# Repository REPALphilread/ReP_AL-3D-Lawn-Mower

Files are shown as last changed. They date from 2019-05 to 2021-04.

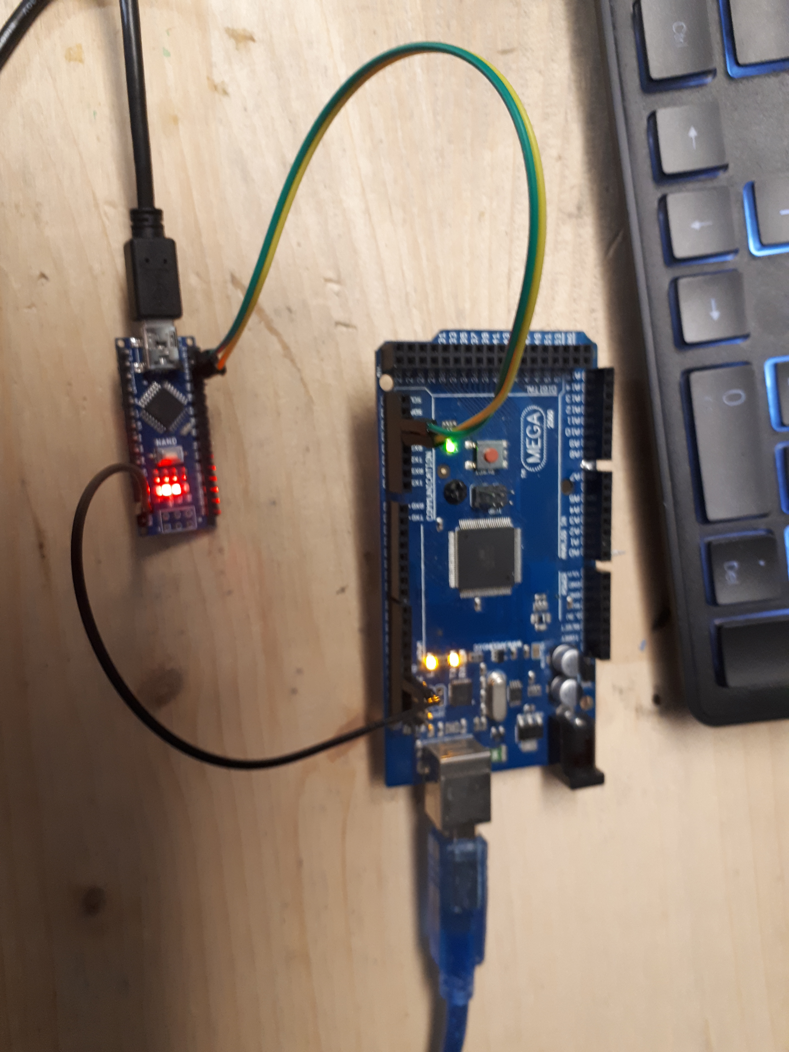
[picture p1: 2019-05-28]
Test Sketches/Test Coms MEGA NANO/MEGA NANO Setup.jpg

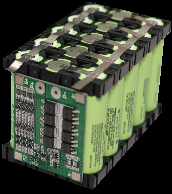
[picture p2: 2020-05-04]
Mower Arduino Code/Mower_V9.2/SDCard BMP/batterypack.bmp

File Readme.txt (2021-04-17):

ReP_AL-3D-Lawn-Mower
Code and Files for the ReP_AL 3D Printed Lawn Mower
---------------------------------------------------

All build instructions and the latest STL files are found at

www.repalmakershop.com

Arduino Code
------------
The mower software is in the folder Mower Arduino Code:  
PLEASE ALWAYS USE THE LATEST VERSION OF THE CODE

Upload the MEGA code to the Arduino MEGA
Upload the Nano code to the Arduino Nano
Upload the NodeMCU code to the NodeMCU Board   (includes new code)
Upload the TFT Code to the TFT MEGA Shield
Upload the ESP32_Rover Code to the ESP32 Board (GPS)
Upload the BMP Files to the TFT SD Card

(I needed to use the "old bootloader" option in the Arduino IDE to get the sketch to upload to the NANO)
Perimeter Wire - Sender_station_V1 needs to be uploaded to the Arduino in the perimeter wire transmitter.

Perimeter Wire Transmitter
--------------------------

Upload the code from this folder to the wire transmitter

Libraries
---------
All the libraries I used for the Arduino Code can be found in this folder.
Ensure these are installed in the Arduino libraries folder otherwise the main code wont compile

Test sketches folder
--------------------
They are designed to test the indiviual components in your build to see if they are working. 
Ihe idea is to debug the components indicudually so you are faster in completing the project.

----------------------------------------------
All my work falls under the GNU Public License
----------------------------------------------

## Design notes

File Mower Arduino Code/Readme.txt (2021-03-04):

---------------------------------------------
This software is protected by the GNU License
---------------------------------------------

PLEASE ALWAYS USE THE LATEST VERSION OF THE CODE!!

Upload the MEGA code to the Arduino MEGA
Upload the Nano code to the Arduino Nano
Upload the NodeMCU code to the NodeMCU Board   (includes new code)
Upload the TFT Code to the TFT MEGA Shield
Upload the ESP32_Rover Code to the ESP32 Board (if using GPS)
Upload the BMP Files to the TFT SD Card

Newest Code Version 9.2    Uploaded 04.03.2020
Please use this version

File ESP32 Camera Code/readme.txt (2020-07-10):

The WEB_CAM Code creates a camera server on the home network.
This allows a high resolution video feed.

The CAM_Blynk code alows the video to be viewed in the Blynk APP.
The video feed can also be viewed in a WEB Browser.
Resolution on this version is poor.

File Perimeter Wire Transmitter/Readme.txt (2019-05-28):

Upload this code to the Arduino in the perimeter wire transmitter station.

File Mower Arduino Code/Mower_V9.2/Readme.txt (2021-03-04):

ReP_AL 3D Printed Robot Lawn Mower
----------------------------------

Code V9.2  10.01.2021
----------------------

Upload the MEGA code to the Arduino MEGA
Upload the Nano code to the Arduino Nano
Upload the NodeMCU code to the NodeMCU Board   (includes new code)
Upload the TFT Code to the TFT MEGA Shield
Upload the ESP32_Rover Code to the ESP32 Board (GPS)
Upload the BMP Files to the TFT SD Card

Features of 9.2
---------------

- Allows all LCD messages to be turned off if using a TFT screen.  This makes the program much more compact when using a TFT screen

In MEGA code line 11
set //#define LCD_KEYPAD for no LCD message
set #define LCD_KEYPAD for LCD messages on

- Major bug fix in the sensors menu.  Now SONAR and WIFI can be accessed again.

Known Issues of 9.0
--------------------
- Communication of button posiitons in the WIFI app not perfected.
- GYRO control not optimised.

Planned for next release
------------------------
- GYRO / Compass options (which device will control the mower)

NodeMCU Board URL:
------------------
Use this URL to add the NodeMCU board 1.0 to the boards menu.

http://arduino.esp8266.com/stable/package_esp8266com_index.json

ESP32 Board URL:
------------------
Use this URL to add the ESP32 DOITDev1.0 board to the boards menu.
https://dl.espressif.com/dl/package_esp32_index.json, http://arduino.esp8266.com/stable/package_esp8266com_index.json

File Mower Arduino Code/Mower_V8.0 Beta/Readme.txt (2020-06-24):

ReP_AL 3D Printed Robot Lawn Mower
----------------------------------

DONT USE THIS VERSION - USE THE 8.2 Version

Code V8.0  BETA    04.05.2020
------------------------------

Upload the MEGA code to the Arduino MEGA
Upload the Nano code to the Arduino Nano
Upload the NodeMCU code to the NodeMCU Board   (includes new code)
Upload the TFT Code to the TFT MEGA Shield
Upload the BMP Files to the TFT SD Card (in the route folder of the SD card)

Features of 8.0 BETA
--------------------

- TFT Display is added (TFT_Screen_Menu = 1 in Settings to turn on TFT function
			Ensure LCD_Scree_Keypad_Menu = 0 )
- Bumper Bar is activated in finding wire function
- Angle Stop Capability added
- Tip Over Safety Stop Capability added

Experimental
- Slow at wire function - Slows the mower when it gets to the wire to ensure the wire is detected in time.

Known Issues of 8.0 BETA
------------------------
- With TFT longer reaction time than normal to detect wire (see slow at wire function to help)
- TFT Some menus get stuck when returning to the home screen
- TFT Test scripts dont always start correctly

NodeMCU Board URL:
------------------
Use this URL to add the NodeMCU board 1.0 to the boards menu.

http://arduino.esp8266.com/stable/package_esp8266com_index.json

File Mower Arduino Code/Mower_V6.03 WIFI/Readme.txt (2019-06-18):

ReP_AL 3D Printed Robot Lawn Mower
----------------------------------

Code V6.03   
------------------------------

Upload the MEGA code to the Arduino MEGA
Upload the Nano code to the Arduino Nano
Upload the NodeMCU code to the NodeMCU Board

Features of 6.03
----------------

- Improved docking logic
- Docking can now be cancelled with the APP by pressing pause.
- Compass now uses degrees instead of heading for heading lock motion (better stability)
- Max_Cycle_Wire_Find set this for the maximum amount of cycles the mower moves forward to find the wire before reseting.

NodeMCU Board URL:
http://arduino.esp8266.com/stable/package_esp8266com_index.json

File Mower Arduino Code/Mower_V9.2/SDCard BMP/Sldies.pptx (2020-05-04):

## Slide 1

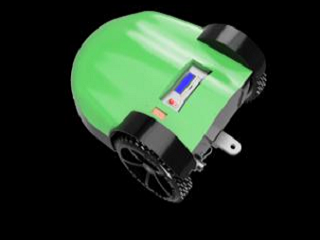
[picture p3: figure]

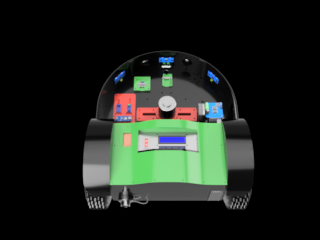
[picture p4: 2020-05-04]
Mower Arduino Code/Mower_V9.2/SDCard BMP/Sensors.bmp

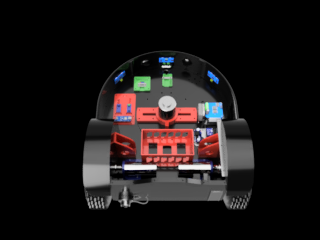
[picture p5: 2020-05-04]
Mower Arduino Code/Mower_V9.2/SDCard BMP/Motors.bmp

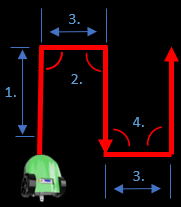
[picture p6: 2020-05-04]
Mower Arduino Code/Mower_V9.2/SDCard BMP/ParallelMow.bmp

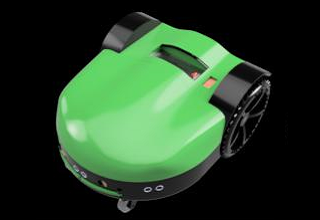
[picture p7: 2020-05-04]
Mower Arduino Code/Mower_V9.2/SDCard BMP/Mower4.bmp

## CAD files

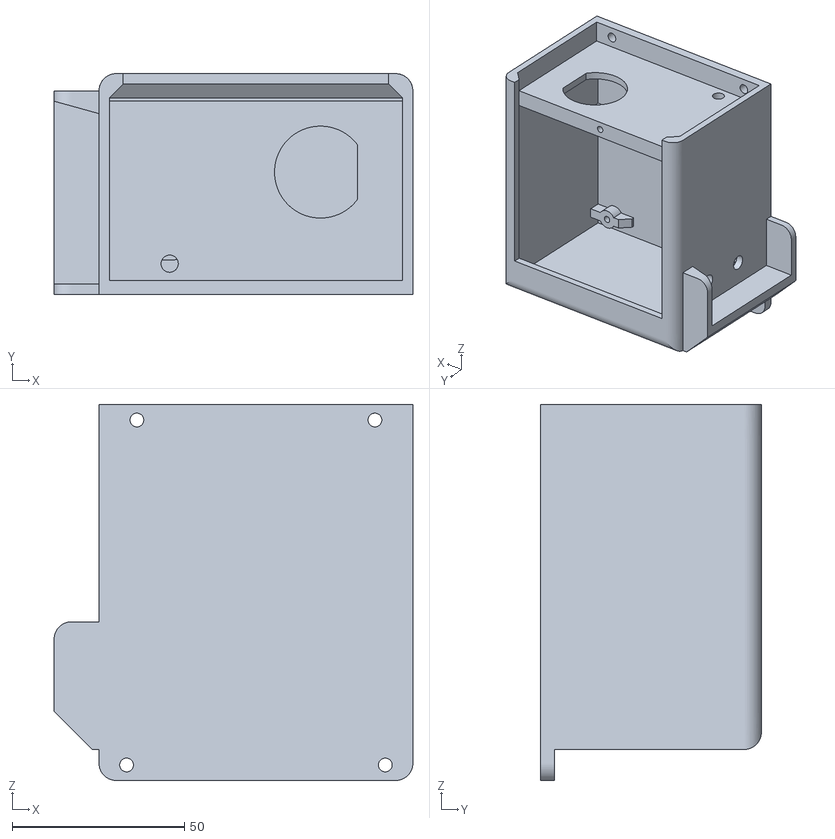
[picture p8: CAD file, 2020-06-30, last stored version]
RTK GPS STL Files/STL RTK Base Station Case/01 Main Case.stl
104.0 x 64.0 x 109.0

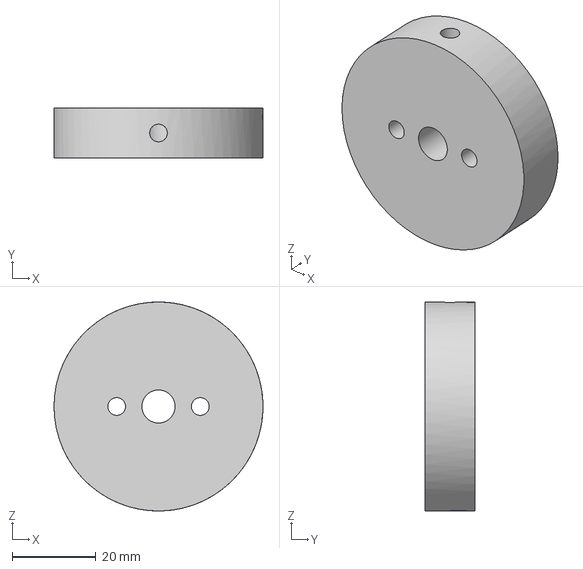
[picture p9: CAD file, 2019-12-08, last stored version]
Metal Parts Step Files/Blade Adapter.step
50.0 x 12.0 x 50.0 mm

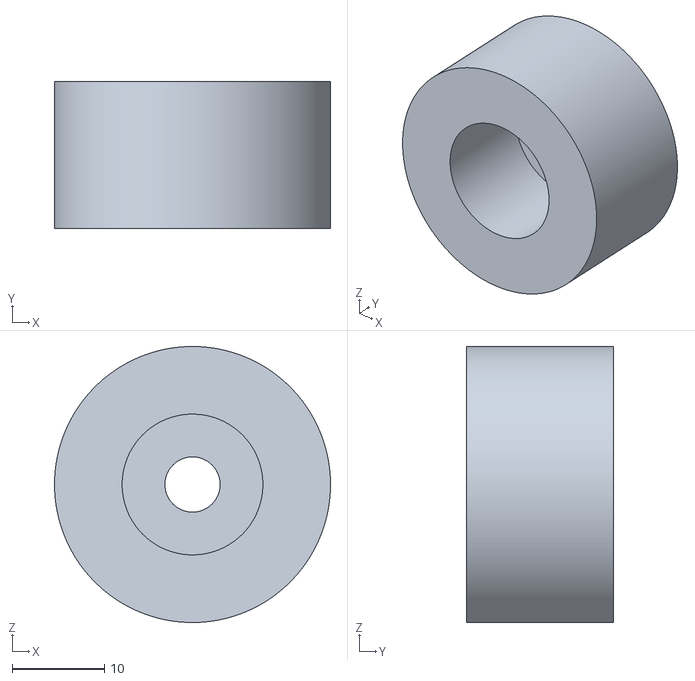
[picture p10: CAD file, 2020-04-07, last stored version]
Metal Parts Step Files/Drill Templates/99 Drill 6mm End Hole Template.stl
30.0 x 16.0 x 30.0

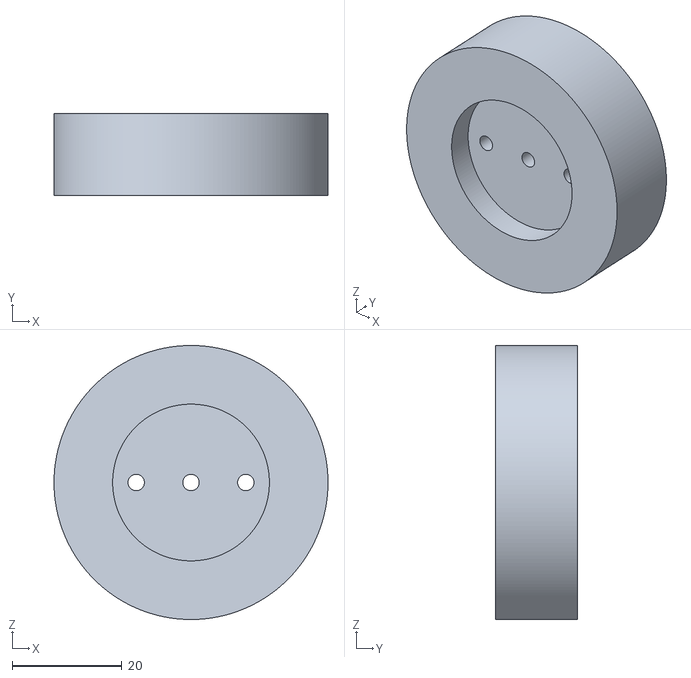
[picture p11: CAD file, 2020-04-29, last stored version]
Metal Parts Step Files/Drill Templates/Blade Motor Adapter/Drill Press/04 Blade Adapter 1 28mm thin.stl
50.0 x 15.0 x 50.0

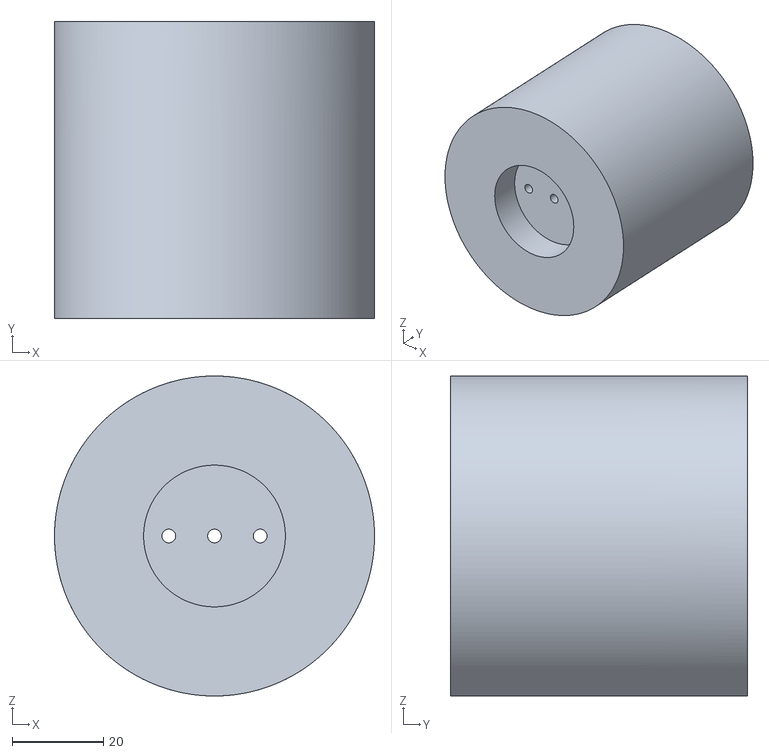
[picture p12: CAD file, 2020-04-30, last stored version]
Metal Parts/Drill Templates/Blade Motor Adapter/Hand Drill/01 Blade Adapter 30mm Hand Drill.stl
70.0 x 65.0 x 70.0

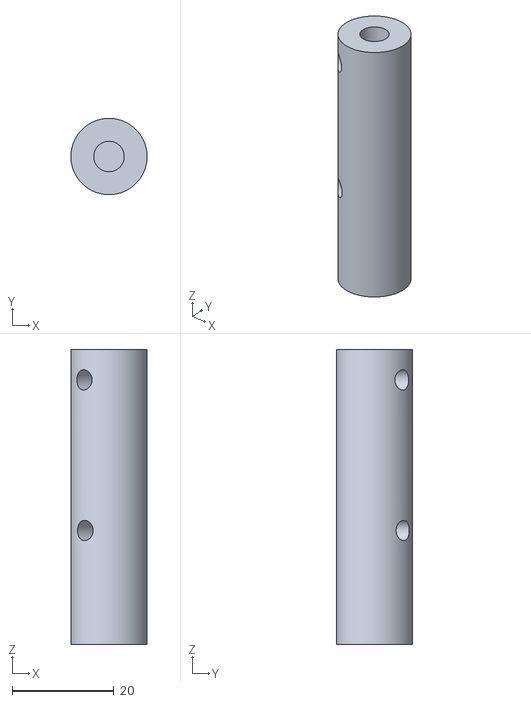
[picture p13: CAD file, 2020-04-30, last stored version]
Metal Parts/STL/Rear Axle - 220.stl
15.0 x 15.0 x 58.0

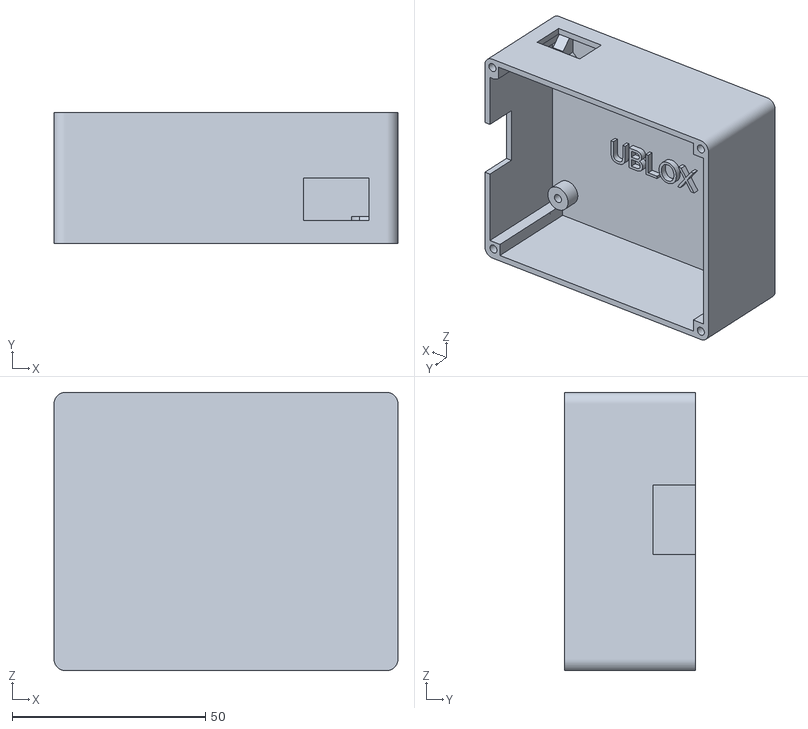
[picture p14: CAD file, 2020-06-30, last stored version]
RTK GPS STL Files/STL RTK GPS Rover Case/ESP32 GPS Case.stl
89.0 x 34.0 x 72.0

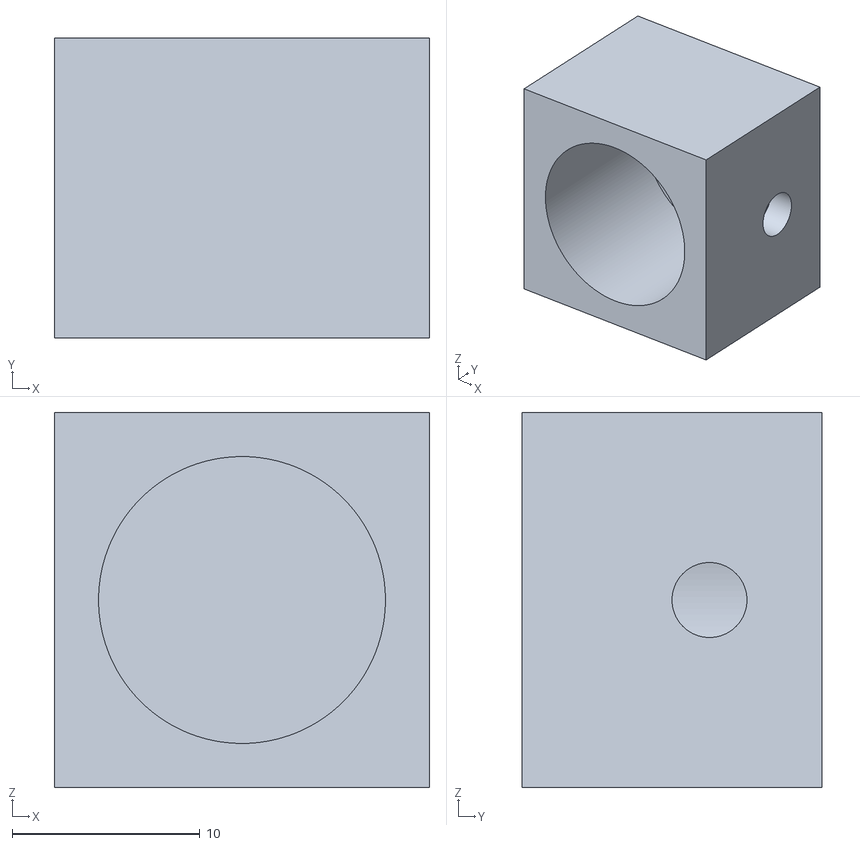
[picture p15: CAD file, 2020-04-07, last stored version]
Metal Parts Step Files/Drill Templates/96 Drill 3mm End Template.stl
20.0 x 16.0 x 20.0

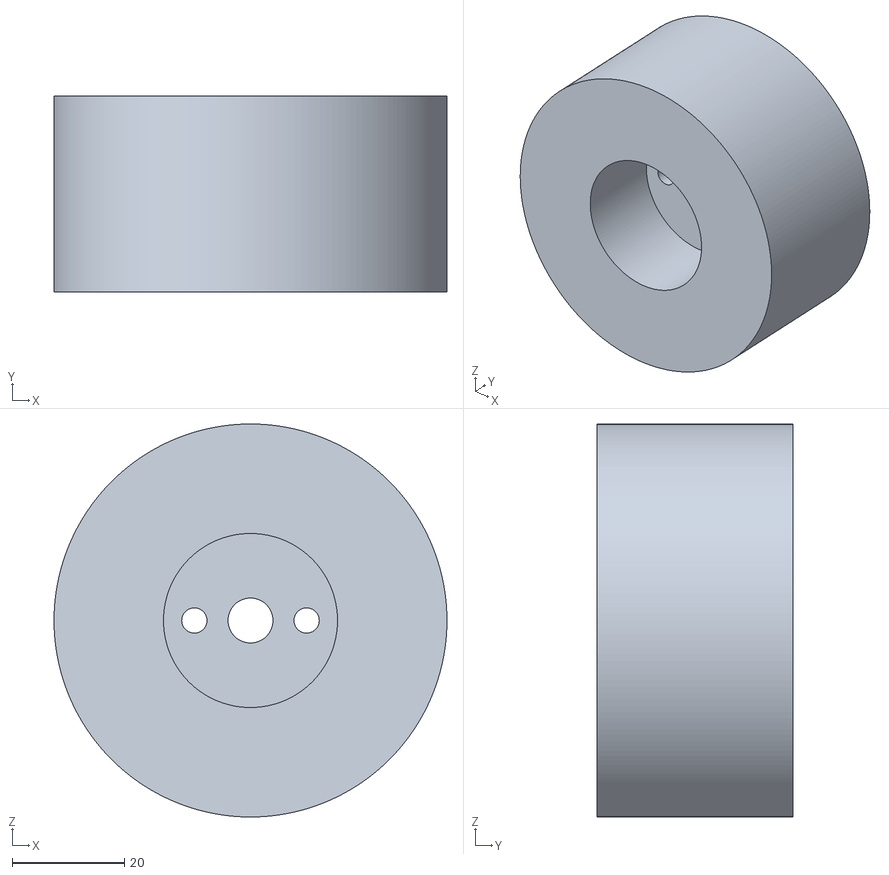
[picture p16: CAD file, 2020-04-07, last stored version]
Metal Parts Step Files/Drill Templates/Blade Motor Adapter/Drill Press/02 Blade Adapter 2.stl
70.0 x 35.0 x 70.0

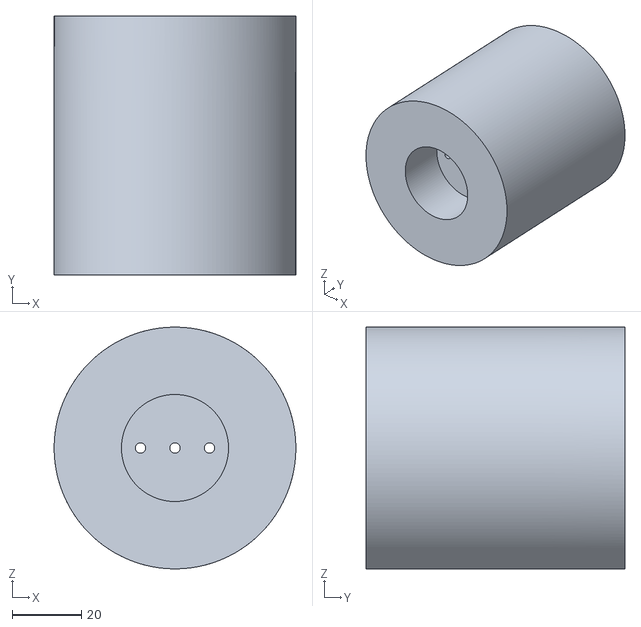
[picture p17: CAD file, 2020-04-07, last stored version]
Metal Parts Step Files/Drill Templates/Blade Motor Adapter/Hand Drill/01 Blade Adapter Hand Drill 1.stl
70.0 x 75.0 x 70.0

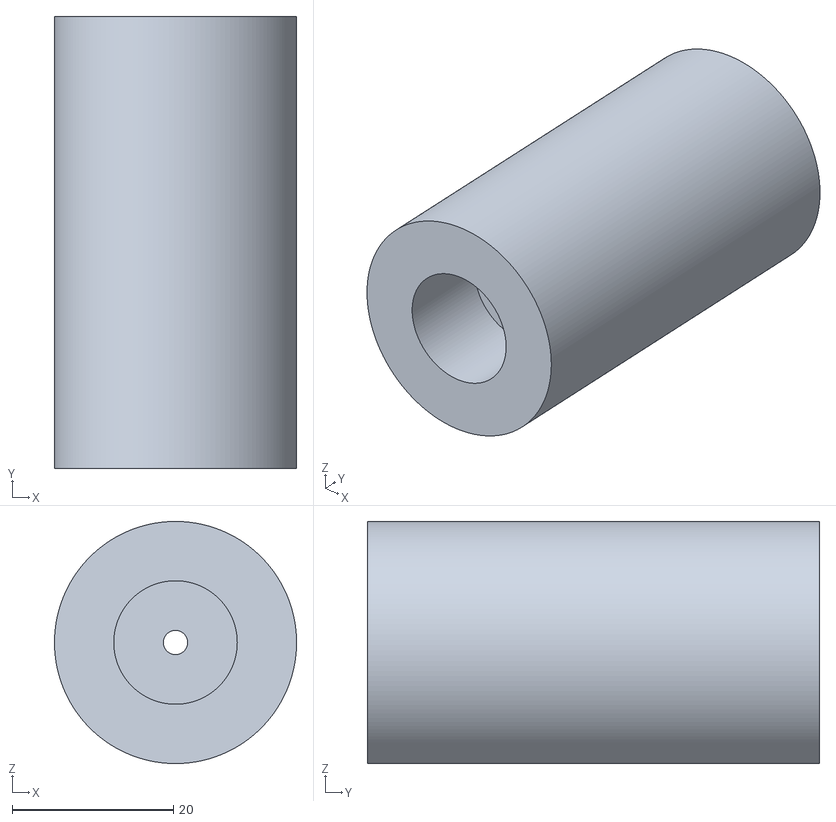
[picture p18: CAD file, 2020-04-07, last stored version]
Metal Parts Step Files/Drill Templates/Wheel Axle/Hand Drill/01 Drill 3mm End Hole Hand Drill Template.stl
30.0 x 56.0 x 30.0

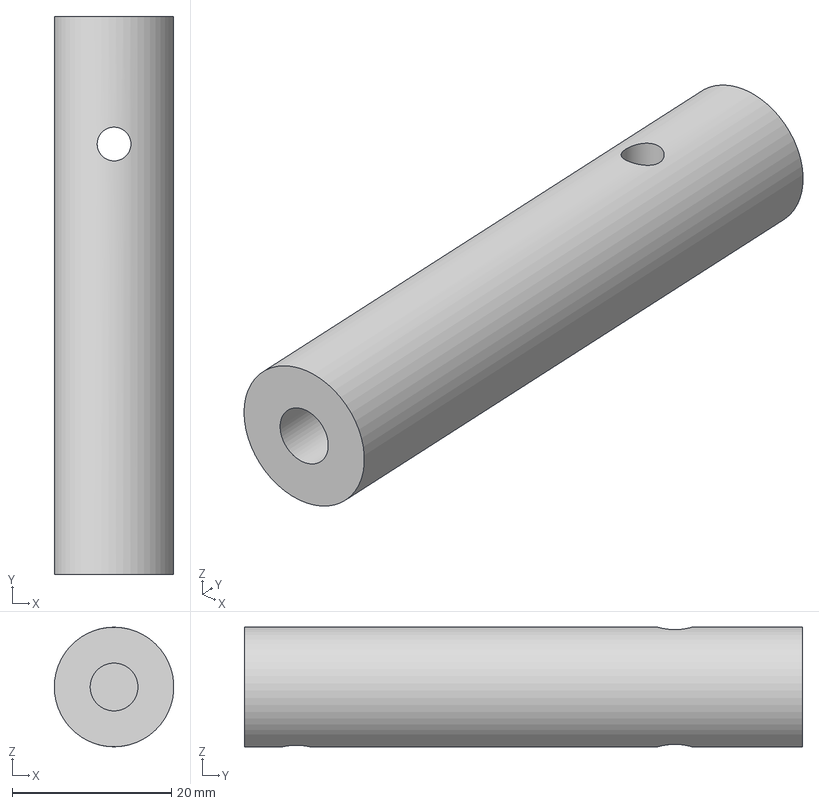
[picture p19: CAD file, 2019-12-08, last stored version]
Metal Parts Step Files/Wheel Axel.step
15.0 x 70.0 x 15.0 mm

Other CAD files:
Metal Parts/Drill Templates/Blade Motor Adapter/Drill Press/01 Drill Press Blade Adapter 30mm.stl
Metal Parts/Drill Templates/Blade Motor Adapter/Hand Drill/02 Blade Adapter 28mm Hand Drill.stl
Metal Parts/Drill Templates/Wheel Axle/Hand Drill/01 Drill Template Hand 3mm Pilot.stl
Metal Parts Step Files/Blade Adapter.stl
Metal Parts Step Files/Drill Templates/95 Drill 5.5mm End Template.stl
Metal Parts Step Files/Drill Templates/95 Drill 5.5mm Set Screw Template.stl
Metal Parts Step Files/Drill Templates/98 Drill 3mm End Hole Template.stl
Metal Parts Step Files/Drill Templates/98 Drill 3mm Set Screw Template.stl
Metal Parts Step Files/Drill Templates/Blade Motor Adapter/Drill Press/01 Blade Adapter 1.stl
Metal Parts Step Files/Drill Templates/Blade Motor Adapter/Drill Press/03 Blade Adapter Set Screw.stl
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

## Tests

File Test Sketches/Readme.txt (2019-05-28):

Description of the test sketches and what they do.
==================================================

I2C_Address_Finder
You will need to run this on the Mower Arduino MEGA to find the address of the LCD screen.  The Adress found then needs to be
inputed into the Mower code so that the MEGA can talk to the LCD screen.

Relay_Test:
If the relay is correctly wired to the MEGA the sketch turns the relay on and off at 1 second intervals.
If the relay is not working check that pin24 is really being used.  The pins are labeled so that its easily done to use the wrong pin.

Test Coms MEGA NANO:
Checks that the serial communication between the MEGA and the NANO is working.
Open the sketch in 2 seperate ARDUINO IDE editors.  then run the serial mointor of the MEGA (Baud 115200) and the NANO (Baud 9600)
If all is working well you should see the same Amps and Volts reading on each serial monitor.

Test Sonar Arrays
Checks the functionality of the SONAR array.  see the readme.txt in the folder for more details

Test Wire Function
Checks that the perimeter wire is working and setup correctly.
Upload the sketch to the Arduino MEGA.  You will need to have the perimeter wire transmitter station running and a minimum 10-20m length of wire running from it.  The amplifier and 11P ferrite sensor will also need to be installed in the mower and connected to the Arduino MEGA as shown in the wiring diagrams (A5).

Mower Blade Test Only
Checks the function of the Mower Blade Motor and motor controller
REMOVE ALL BLADES from the mower disc when running this test!

Wheel Motor Test
Checks correct operation of the rear drive wheels

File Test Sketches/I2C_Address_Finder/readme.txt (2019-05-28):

Upload the code to the Arduino MEGA in the mower.  Ensure that the LCD is powered on and connected to the 
SCL SCA pins on the MEGA as shwon on my website.

Run the sketch and open the serial monitor.  Note down the address shown and update the MOWER code with this address

LiquidCrystal_I2C lcd(0x27, 2, 1, 0, 4, 5, 6, 7, 3, POSITIVE); 

The 0x27 parts needs to be updated with whatever address your LCD screen has.

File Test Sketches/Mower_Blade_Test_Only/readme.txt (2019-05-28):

 ReP_AL Mower Test Sketch
 --------------------------
 
 Ensure ALL the mower blades are removed for this test
 This sketch will test the function of the Mower Motor controller and mower blade motor
 ------------------------------------------------------------------------------
 Please modify the I2C address of your LCD display to see the LCD infomation
 ------------------------------------------------------------------------------
 The sketch will spin the blade motor to the set PWM speed you set as PWM Blade Speed.
 After a few seconds the blade will stop and then restart.
 
 Please be careful remove all the blades from the cutting disc and ensure nothing is 
 underneath the mower which can be hit by the cutting disc or motor shaft

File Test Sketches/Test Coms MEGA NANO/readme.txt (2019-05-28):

    -------------------------------------------------------
    Make sure that the I2C address of the LCD is updated!!!
    -------------------------------------------------------

    See the attached pictures for the wiring setup of the MEGA and the NANO.
    This is the same setup as in the MOWER.

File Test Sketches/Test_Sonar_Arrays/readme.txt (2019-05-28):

    SONAR TESTING SKETCH
    ==========================================

    -------------------------------------------------------
    Make sure that the I2C address of th LCD is updated!!!
    -------------------------------------------------------
    
    This test sketch will check the installation of the Sonar Array.  
    Load this to the MEGA in the mower with the sonar array wired up.
    
    It is very important that the Sonar array works correctly.  1. to avoid stuff and 2. if the sonar is not working
    correctly it will increase the loop time of the software considerably.

    The software will wait for the sonar to ping.  If there is no return signal the software will wait around looking for it.
    This is not good for the performance of the mower.  It needs to detect wires etc immediatley.

    In the setup you can turn on or off the individual sonars.
    
    1 = ON    0 = OFF
    bool Sonar_1_Activat            = 1;                        
    bool Sonar_2_Activate           = 1;                         
    bool Sonar_3_Activate           = 1; 

    LCD Displays following
    Sonar 2       Sonar 1         Sonar  3
    distance 2    distance 1      distance 3
    
    All OK
    ======
    If you place your hand in front of each sonar the distance decraeses on the correspoding LCD display
    this happens for all 3 sonars and the position of the sonar reading on the LCD corresponds to the sonar module
    being tested.

    Sonar registers but the LCD display changes in the wrong place.
    ===============================================================
    Your wiring is switched.  Pleaese check the Tri and Echo pins for each sonar are connected to the right PIN
    on the MEGA.  If you run like this the mower will turn into the obsticle its trying to avoid

    SONAR Reads 999
    ===============
    The sonar signal is not being read by the software.  
      Check wiring  (refernec diagram on the website)
      Check 5V is present at that sonar
      Check continuity on all the wires from the MEGA pin to the pin on the Sonar module
      Check there is not wiggle contact (pin is not sitting correctly in the plug)
      Check that Trig and Echo pins are not mixed up.
      Check...check...check....

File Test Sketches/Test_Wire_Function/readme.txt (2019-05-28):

     
     -------------------------------------------------------
     Make sure that the I2C address of th LCD is updated!!!
     -------------------------------------------------------

     You can use a Laptop and the Serial mointor to do this check but its better with the Mower and the LCD screen
     The LCD screen needs to be working (i.e. you know your I2C address)
     Add this I2C address to the sketch to activate the LCD screen
     This sketch is desgined to detect the boundary wire in your garden.
     Holding the mower in your hands (no motors on/no blades spinning!!) move around the garden and over the boundary wire.
     IN/OUT :  Displays if you are inside or outside of the wire loop
     MAG : Shows the magnitude of the wire signal   -ve is inside the loop  /   +ve outside the loop
     
     All OK
     ======
     You are inside the mowing area and the display shows IN & You have a -ve MAG reading in the 1000's
     You are outisde the mowing area and the LCD display shows OUT & you have a +ve MAG reading
     You are directly over the wire and you have an IN/OUT flicker and the MAG reading is low or around 0.
     
     Inside Outside Flipped
     ======================
     If you are reading IN when you hold the mower outside the loop and OUT when you are inside the loop then 
     it means your sensor and boundary wire are working (good news!), only the signal is flipped :)
     Solution: switch the boundary wires on your sender station terminals or switch the 11P ferrite sensor on the amplifier
     so the legs from the 11P ferite sensor are the other way around.
     
     Low MAG Readings
     ================
     The MAG reading is only in the 100's.  The adjust the amplifier screw so that the signal is strengthend and you now
     get readings in the 1000's Inside and Outside the Wire

     Nothing Happens
     ===============
     Check the wiring diagram again and all is connected as in the diagram.
     Check the correct pin is being used on the MEGA for the amplifier.
     Check the Amplifier has 5V power
     Check the sketch is uploaded to the perimeter wire transmitter
     Check your Garden wire loop is closed and has no breaks in it.
     Check you have enough power to the perimeter wire transmitter
     Check the continuity of all wires on the perimeter sensor
     There is a problem somehere.......    :)

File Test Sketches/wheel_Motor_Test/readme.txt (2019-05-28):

Wheel Motor Test
----------------

Remove all cutting blades before testing!!
Update your LCD I2C address.

This sketch tests the function of the rear wheel drive motors.
If the mower turns opposite to the direction shown change the setting

bool Reverse_Steering           = 1;   

to either 1 or 0.

Not Working
-----------
- Check the correct wiring of the motors to the motor driver.
- Check there are no loose wires or connections at the Arduino Pins
- Ensure the wheel motors are not jammed by too long screws attaching it to the wheel arch.
- Check jumpers are removed/installed on the motor bridge
- Check the pins are correctly plugged into the Arduino
- Check you have a 12V supply to the motor driver (relay working? switch off?)
- Check the 12V circuit diagram and test for a 12V supply voltage on the motor driver.
- Check 12V +ve and -ve wires are correct.

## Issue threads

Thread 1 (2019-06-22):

spirale mode

shamanic50, 2019-06-22:
Hi, I tried to create a spirale mode. I would to use this mode when in friend house without perimeter wire.
The code in "specials"

"
void Special_Cut_Under_Trampoline_Function() {
  //Enter Code Here
  lcd.clear();
    lcd.print("Place Mower at");
    lcd.setCursor(0,1);
    lcd.print("trampoline legs");
    delay(5000);
    lcd.clear();
    lcd.print("Press Start >");
    int GO = 0;
    while (GO == 0) {
          Read_Membrane_Keys();
          delay(100);
          if(!Start_Key_X){
            GO = 1;
            }
        }  // end of while loop

    lcd.clear();
    digitalWrite(Relay_Motors, LOW);
    lcd.print("3....");
    Motor_Action_Spin_Blades();
    delay(1000);
    lcd.clear();
    lcd.print("2....");
    delay(1000);
    lcd.clear();
    lcd.print("1....");
    delay(1000);
    lcd.clear();
    lcd.print("GO!!!!!!");
    delay(1000);
   int tourtime=12000; // circle tourtime. it is about intersection areas between each spiral. it should be less than circle time
    int increasetime=3000; // time for next tour, larger spiral needs more time
    int numberofspiral=3000; // number of circle
    int minspeed=80; // initial speed for spiral.
    int maxspeed=255;// max speed

    SetPins_ToGoForwards();
    Motor_Action_Go_Full_Speed();
    delay(100);
          PWM_MaxSpeed_RH = maxspeed;
    for(int i=0;i<=numberofspiral;i++) {
       PWM_MaxSpeed_LH = minspeed;
  Motor_Action_Go_Full_Speed();
       minspeed=minspeed*1.1;// increase the speed to increase radius
       delay(tourtime);
       tourtime=tourtime+(increasetime*1.1); // increase the time for scan optimum area
     }
     delay(150);
  Motor_Action_Stop_Spin_Blades();
  Motor_Action_Stop_Motors();

  lcd.clear();
  lcd.print("Finished");
  delay(5000);
  lcd.clear();
}

"

REPALphilread, 2019-10-15:
Thanks for the code.  I tried to integrate the spiral feature into Code 6.6 onwards.
Phil.

Closed 2019-10-15.

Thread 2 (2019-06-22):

limited Battery current

shamanic50, 2019-06-22:
Hi,
Thank for your work!
In the version 5.1, my battery was to little for the blade motor start at max. So i create a little code to start progressively the blade :

int  PWM_Blade_Speed_Min = 150
void SpinBlades()
{
  if (Blades_ON == 1) {                                       // Blades are turn ON in settings and will spin!
    delay(20);
    digitalWrite(R_EN, HIGH);
    digitalWrite(L_EN, HIGH);
    delay(20);
    while (PWM_Blade_Speed_Min<PWM_Blade_Speed){
    analogWrite(RPWM, PWM_Blade_Speed_Min);
    PWM_Blade_Speed_Min +=5;
    delay(40);
    }
    analogWrite(RPWM, PWM_Blade_Speed);
    delay(20);
    Serial.println("Blade Motor Spinning.. Mind your fingers!");
  }         

  if (Blades_ON == 0) {                                     // Blades are turn off in settings and will not spin!
    void StopSpinBlades();
    Serial.println("TEST MODE - BLADES STOPPED!");
  }
}

void StopSpinBlades()  {
  delay(20);
  digitalWrite(R_EN, LOW);
  digitalWrite(L_EN, LOW);
  PWM_Blade_Speed_Min=10;
  delay(20);
  Serial.println("Blades Motor Stopped...!");
}

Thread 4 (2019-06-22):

Add Bumper?

shamanic50, 2019-06-22:
sometimes distance sensor doesn't work or the obstacle is to small like chair, can you add two bumper like micro switch to have a collision sensor ?

thank you.

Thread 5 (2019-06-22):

drop sensor

shamanic50, 2019-06-22:
For security reason, i would like to have a sensor to stop the blade if the mower is not on the floor, or return.
Maybe an IMU sensor with accelerometer ?
or distance sensor which return distance between the floor and the mower

thank you very mutch for this project!

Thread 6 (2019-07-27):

Is Nano board really necessary inside robot?

eimix, 2019-07-27:
In library adcman/adcman.h is written:
"- WARNING: never use any 'analogRead()' in your code when using this class!"

This warning prevents using standard arduino functions, but it provides it's own functionality. Analog inputs could be read using this library:

Setup ADC pin:     ADCMan.setCapture(pinMotorMowSense, 1, 1);
Program loop:
     ADCMan.run();
     if (ADCMan.isCaptureComplete(pinMotorMowSense)){
        int value = ADCMan.read(pinMotorMowSense);
     }

Is there any other limitation that makes Nano board necessary?

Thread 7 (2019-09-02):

Cant upload to ardunio board

sambenoit, 2019-09-02:
I get the error ever time cant find Drivers.H where is this download.Is their a better step by step guide?

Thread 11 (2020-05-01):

fichier tft et image

willys10, 2020-05-01:
bonjour

 pouvez vous me dire dans quel dossier sont ranges les fichiers TFT et image ?

merci

comperta, 2020-06-16:
Hello Willys10,

si tu n'as pas déjà trouvé :
tu trouveras les fichiers dans ReP_AL-3D-Lawn-Mower/Mower Arduino Code/
=> ouvre le zip "Mower_V8.0 Beta 2.zip"
dedans tu as deux dossier TFT_V1.0 et SDCard BMP

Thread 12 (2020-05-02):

Nema17 stepper motor or bldc hub motor from hover board

kris86k, 2020-05-02:
I have some strong power nema17 stepper and bldc hub motor from hover board. Its possible way to connect?

Starsurfer78, 2020-11-14:
You need BLDC Motor Driver and find out how they work.

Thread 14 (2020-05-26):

'Day' in 'class Time' does not name a type

Mateuszz21, 2020-05-26:
Hello, I'm having trouble loading the MEGA_V8.0 code
I have no idea how to solve this. I added the author's library, but it didn't help
Error description

Arduino:1.8.12 (Windows 10), Płytka:"Arduino Mega or Mega 2560, ATmega2560 (Mega 2560)"

C:\Programy\Arduino\arduino-builder -dump-prefs -logger=machine -hardware C:\Programy\Arduino\hardware -hardware C:\Users\sitek\AppData\Local\Arduino15\packages -tools C:\Programy\Arduino\tools-builder -tools C:\Programy\Arduino\hardware\tools\avr -tools C:\Users\sitek\AppData\Local\Arduino15\packages -built-in-libraries C:\Programy\Arduino\libraries -libraries C:\Users\sitek\OneDrive\Pulpit\libraries -fqbn=arduino:avr:mega:cpu=atmega2560 -ide-version=10812 -build-path C:\Users\sitek\AppData\Local\Temp\arduino_build_26787 -warnings=all -build-cache C:\Users\sitek\AppData\Local\Temp\arduino_cache_512625 -prefs=build.warn_data_percentage=75 -prefs=runtime.tools.arduinoOTA.path=C:\Programy\Arduino\hardware\tools\avr -prefs=runtime.tools.arduinoOTA-1.3.0.path=C:\Programy\Arduino\hardware\tools\avr -prefs=runtime.tools.avrdude.path=C:\Programy\Arduino\hardware\tools\avr -prefs=runtime.tools.avrdude-6.3.0-arduino17.path=C:\Programy\Arduino\hardware\tools\avr -prefs=runtime.tools.avr-gcc.path=C:\Programy\Arduino\hardware\tools\avr -prefs=runtime.tools.avr-gcc-7.3.0-atmel3.6.1-arduino5.path=C:\Programy\Arduino\hardware\tools\avr -verbose C:\Users\sitek\AppData\Local\Temp\arduino_modified_sketch_80592\MEGA_V8.0.ino
C:\Programy\Arduino\arduino-builder -compile -logger=machine -hardware C:\Programy\Arduino\hardware -hardware C:\Users\sitek\AppData\Local\Arduino15\packages -tools C:\Programy\Arduino\tools-builder -tools C:\Programy\Arduino\hardware\tools\avr -tools C:\Users\sitek\AppData\Local\Arduino15\packages -built-in-libraries C:\Programy\Arduino\libraries -libraries C:\Users\sitek\OneDrive\Pulpit\libraries -fqbn=arduino:avr:mega:cpu=atmega2560 -ide-version=10812 -build-path C:\Users\sitek\AppData\Local\Temp\arduino_build_26787 -warnings=all -build-cache C:\Users\sitek\AppData\Local\Temp\arduino_cache_512625 -prefs=build.warn_data_percentage=75 -prefs=runtime.tools.arduinoOTA.path=C:\Programy\Arduino\hardware\tools\avr -prefs=runtime.tools.arduinoOTA-1.3.0.path=C:\Programy\Arduino\hardware\tools\avr -prefs=runtime.tools.avrdude.path=C:\Programy\Arduino\hardware\tools\avr -prefs=runtime.tools.avrdude-6.3.0-arduino17.path=C:\Programy\Arduino\hardware\tools\avr -prefs=runtime.tools.avr-gcc.path=C:\Programy\Arduino\hardware\tools\avr -prefs=runtime.tools.avr-gcc-7.3.0-atmel3.6.1-arduino5.path=C:\Programy\Arduino\hardware\tools\avr -verbose C:\Users\sitek\AppData\Local\Temp\arduino_modified_sketch_80592\MEGA_V8.0.ino
Using board 'mega' from platform in folder: C:\Programy\Arduino\hardware\arduino\avr
Using core 'arduino' from platform in folder: C:\Programy\Arduino\hardware\arduino\avr
Detecting libraries used...
"C:\\Programy\\Arduino\\hardware\\tools\\avr/bin/avr-g++" -c -g -Os -w -std=gnu++11 -fpermissive -fno-exceptions -ffunction-sections -fdata-sections -fno-threadsafe-statics -Wno-error=narrowing -flto -w -x c++ -E -CC -mmcu=atmega2560 -DF_CPU=16000000L -DARDUINO=10812 -DARDUINO_AVR_MEGA2560 -DARDUINO_ARCH_AVR "-IC:\\Programy\\Arduino\\hardware\\arduino\\avr\\cores\\arduino" "-IC:\\Programy\\Arduino\\hardware\\arduino\\avr\\variants\\mega" "C:\\Users\\sitek\\AppData\\Local\\Temp\\arduino_build_26787\\sketch\\MEGA_V8.0.ino.cpp" -o nul
Alternatives for Wire.h: [Wire@1.0]
ResolveLibrary(Wire.h)
  -> candidates: [Wire@1.0]
"C:\\Programy\\Arduino\\hardware\\tools\\avr/bin/avr-g++" -c -g -Os -w -std=gnu++11 -fpermissive -fno-exceptions -ffunction-sections -fdata-sections -fno-threadsafe-statics -Wno-error=narrowing -flto -w -x c++ -E -CC -mmcu=atmega2560 -DF_CPU=16000000L -DARDUINO=10812 -DARDUINO_AVR_MEGA2560 -DARDUINO_ARCH_AVR "-IC:\\Programy\\Arduino\\hardware\\arduino\\avr\\cores\\arduino" "-IC:\\Programy\\Arduino\\hardware\\arduino\\avr\\variants\\mega" "-IC:\\Programy\\Arduino\\hardware\\arduino\\avr\\libraries\\Wire\\src" "C:\\Users\\sitek\\AppData\\Local\\Temp\\arduino_build_26787\\sketch\\MEGA_V8.0.ino.cpp" -o nul
Alternatives for drivers.h: [drivers]
ResolveLibrary(drivers.h)
  -> candidates: [drivers]
"C:\\Programy\\Arduino\\hardware\\tools\\avr/bin/avr-g++" -c -g -Os -w -std=gnu++11 -fpermissive -fno-exceptions -ffunction-sections -fdata-sections -fno-threadsafe-statics -Wno-error=narrowing -flto -w -x c++ -E -CC -mmcu=atmega2560 -DF_CPU=16000000L -DARDUINO=10812 -DARDUINO_AVR_MEGA2560 -DARDUINO_ARCH_AVR "-IC:\\Programy\\Arduino\\hardware\\arduino\\avr\\cores\\arduino" "-IC:\\Programy\\Arduino\\hardware\\arduino\\avr\\variants\\mega" "-IC:\\Programy\\Arduino\\hardware\\arduino\\avr\\libraries\\Wire\\src" "-IC:\\Programy\\Arduino\\libraries\\drivers" "C:\\Users\\sitek\\AppData\\Local\\Temp\\arduino_build_26787\\sketch\\MEGA_V8.0.ino.cpp" -o nul
Alternatives for EEPROM.h: [EEPROM@2.0]
ResolveLibrary(EEPROM.h)
  -> candidates: [EEPROM@2.0]
"C:\\Programy\\Arduino\\hardware\\tools\\avr/bin/avr-g++" -c -g -Os -w -std=gnu++11 -fpermissive -fno-exceptions -ffunction-sections -fdata-sections -fno-threadsafe-statics -Wno-error=narrowing -flto -w -x c++ -E -CC -mmcu=atmega2560 -DF_CPU=16000000L -DARDUINO=10812 -DARDUINO_AVR_MEGA2560 -DARDUINO_ARCH_AVR "-IC:\\Programy\\Arduino\\hardware\\arduino\\avr\\cores\\arduino" "-IC:\\Programy\\Arduino\\hardware\\arduino\\avr\\variants\\mega" "-IC:\\Programy\\Arduino\\hardware\\arduino\\avr\\libraries\\Wire\\src" "-IC:\\Programy\\Arduino\\libraries\\drivers" "-IC:\\Programy\\Arduino\\hardware\\arduino\\avr\\libraries\\EEPROM\\src" "C:\\Users\\sitek\\AppData\\Local\\Temp\\arduino_build_26787\\sketch\\MEGA_V8.0.ino.cpp" -o nul
Alternatives for adcman.h: [adcman]
ResolveLibrary(adcman.h)
  -> candidates: [adcman]
"C:\\Programy\\Arduino\\hardware\\tools\\avr/bin/avr-g++" -c -g -Os -w -std=gnu++11 -fpermissive -fno-exceptions -ffunction-sections -fdata-sections -fno-threadsafe-statics -Wno-error=narrowing -flto -w -x c++ -E -CC -mmcu=atmega2560 -DF_CPU=16000000L -DARDUINO=10812 -DARDUINO_AVR_MEGA2560 -DARDUINO_ARCH_AVR "-IC:\\Programy\\Arduino\\hardware\\arduino\\avr\\cores\\arduino" "-IC:\\Programy\\Arduino\\hardware\\arduino\\avr\\variants\\mega" "-IC:\\Programy\\Arduino\\hardware\\arduino\\avr\\libraries\\Wire\\src" "-IC:\\Programy\\Arduino\\libraries\\drivers" "-IC:\\Programy\\Arduino\\hardware\\arduino\\avr\\libraries\\EEPROM\\src" "-IC:\\Programy\\Arduino\\libraries\\adcman" "C:\\Users\\sitek\\AppData\\Local\\Temp\\arduino_build_26787\\sketch\\MEGA_V8.0.ino.cpp" -o nul
Alternatives for perimeter.h: [perimeter]
ResolveLibrary(perimeter.h)
  -> candidates: [perimeter]
"C:\\Programy\\Arduino\\hardware\\tools\\avr/bin/avr-g++" -c -g -Os -w -std=gnu++11 -fpermissive -fno-exceptions -ffunction-sections -fdata-sections -fno-threadsafe-statics -Wno-error=narrowing -flto -w -x c++ -E -CC -mmcu=atmega2560 -DF_CPU=16000000L -DARDUINO=10812 -DARDUINO_AVR_MEGA2560 -DARDUINO_ARCH_AVR "-IC:\\Programy\\Arduino\\hardware\\arduino\\avr\\cores\\arduino" "-IC:\\Programy\\Arduino\\hardware\\arduino\\avr\\variants\\mega" "-IC:\\Programy\\Arduino\\hardware\\arduino\\avr\\libraries\\Wire\\src" "-IC:\\Programy\\Arduino\\libraries\\drivers" "-IC:\\Programy\\Arduino\\hardware\\arduino\\avr\\libraries\\EEPROM\\src" "-IC:\\Programy\\Arduino\\libraries\\adcman" "-IC:\\Programy\\Arduino\\libraries\\perimeter" "C:\\Users\\sitek\\AppData\\Local\\Temp\\arduino_build_26787\\sketch\\MEGA_V8.0.ino.cpp" -o nul
Alternatives for DS1302.h: [arduino-ds1302-master DS1302_RTC]
ResolveLibrary(DS1302.h)
  -> candidates: [arduino-ds1302-master DS1302_RTC]
"C:\\Programy\\Arduino\\hardware\\tools\\avr/bin/avr-g++" -c -g -Os -w -std=gnu++11 -fpermissive -fno-exceptions -ffunction-sections -fdata-sections -fno-threadsafe-statics -Wno-error=narrowing -flto -w -x c++ -E -CC -mmcu=atmega2560 -DF_CPU=16000000L -DARDUINO=10812 -DARDUINO_AVR_MEGA2560 -DARDUINO_ARCH_AVR "-IC:\\Programy\\Arduino\\hardware\\arduino\\avr\\cores\\arduino" "-IC:\\Programy\\Arduino\\hardware\\arduino\\avr\\variants\\mega" "-IC:\\Programy\\Arduino\\hardware\\arduino\\avr\\libraries\\Wire\\src" "-IC:\\Programy\\Arduino\\libraries\\drivers" "-IC:\\Programy\\Arduino\\hardware\\arduino\\avr\\libraries\\EEPROM\\src" "-IC:\\Programy\\Arduino\\libraries\\adcman" "-IC:\\Programy\\Arduino\\libraries\\perimeter" "-IC:\\Programy\\Arduino\\libraries\\DS1302_RTC" "C:\\Users\\sitek\\AppData\\Local\\Temp\\arduino_build_26787\\sketch\\MEGA_V8.0.ino.cpp" -o nul
Alternatives for LiquidCrystal_I2C.h: [NewliquidCrystal]
ResolveLibrary(LiquidCrystal_I2C.h)
  -> candidates: [NewliquidCrystal]
"C:\\Programy\\Arduino\\hardware\\tools\\avr/bin/avr-g++" -c -g -Os -w -std=gnu++11 -fpermissive -fno-exceptions -ffunction-sections -fdata-sections -fno-threadsafe-statics -Wno-error=narrowing -flto -w -x c++ -E -CC -mmcu=atmega2560 -DF_CPU=16000000L -DARDUINO=10812 -DARDUINO_AVR_MEGA2560 -DARDUINO_ARCH_AVR "-IC:\\Programy\\Arduino\\hardware\\arduino\\avr\\cores\\arduino" "-IC:\\Programy\\Arduino\\hardware\\arduino\\avr\\variants\\mega" "-IC:\\Programy\\Arduino\\hardware\\arduino\\avr\\libraries\\Wire\\src" "-IC:\\Programy\\Arduino\\libraries\\drivers" "-IC:\\Programy\\Arduino\\hardware\\arduino\\avr\\libraries\\EEPROM\\src" "-IC:\\Programy\\Arduino\\libraries\\adcman" "-IC:\\Programy\\Arduino\\libraries\\perimeter" "-IC:\\Programy\\Arduino\\libraries\\DS1302_RTC" "-IC:\\Programy\\Arduino\\libraries\\NewliquidCrystal" "C:\\Users\\sitek\\AppData\\Local\\Temp\\arduino_build_26787\\sketch\\MEGA_V8.0.ino.cpp" -o nul
Alternatives for TimeLib.h: [Time@1.5 Time-master@1.6]
ResolveLibrary(TimeLib.h)
  -> candidates: [Time@1.5 Time-master@1.6]
"C:\\Programy\\Arduino\\hardware\\tools\\avr/bin/avr-g++" -c -g -Os -w -std=gnu++11 -fpermissive -fno-exceptions -ffunction-sections -fdata-sections -fno-threadsafe-statics -Wno-error=narrowing -flto -w -x c++ -E -CC -mmcu=atmega2560 -DF_CPU=16000000L -DARDUINO=10812 -DARDUINO_AVR_MEGA2560 -DARDUINO_ARCH_AVR "-IC:\\Programy\\Arduino\\hardware\\arduino\\avr\\cores\\arduino" "-IC:\\Programy\\Arduino\\hardware\\arduino\\avr\\variants\\mega" "-IC:\\Programy\\Arduino\\hardware\\arduino\\avr\\libraries\\Wire\\src" "-IC:\\Programy\\Arduino\\libraries\\drivers" "-IC:\\Programy\\Arduino\\hardware\\arduino\\avr\\libraries\\EEPROM\\src" "-IC:\\Programy\\Arduino\\libraries\\adcman" "-IC:\\Programy\\Arduino\\libraries\\perimeter" "-IC:\\Programy\\Arduino\\libraries\\DS1302_RTC" "-IC:\\Programy\\Arduino\\libraries\\NewliquidCrystal" "-IC:\\Users\\sitek\\OneDrive\\Pulpit\\libraries\\Time-master" "C:\\Users\\sitek\\AppData\\Local\\Temp\\arduino_build_26787\\sketch\\MEGA_V8.0.ino.cpp" -o nul
Alternatives for TimeAlarms.h: [TimeAlarms-master@1.5]
ResolveLibrary(TimeAlarms.h)
  -> candidates: [TimeAlarms-master@1.5]
"C:\\Programy\\Arduino\\hardware\\tools\\avr/bin/avr-g++" -c -g -Os -w -std=gnu++11 -fpermissive -fno-exceptions -ffunction-sections -fdata-sections -fno-threadsafe-statics -Wno-error=narrowing -flto -w -x c++ -E -CC -mmcu=atmega2560 -DF_CPU=16000000L -DARDUINO=10812 -DARDUINO_AVR_MEGA2560 -DARDUINO_ARCH_AVR "-IC:\\Programy\\Arduino\\hardware\\arduino\\avr\\cores\\arduino" "-IC:\\Programy\\Arduino\\hardware\\arduino\\avr\\variants\\mega" "-IC:\\Programy\\Arduino\\hardware\\arduino\\avr\\libraries\\Wire\\src" "-IC:\\Programy\\Arduino\\libraries\\drivers" "-IC:\\Programy\\Arduino\\hardware\\arduino\\avr\\libraries\\EEPROM\\src" "-IC:\\Programy\\Arduino\\libraries\\adcman" "-IC:\\Programy\\Arduino\\libraries\\perimeter" "-IC:\\Programy\\Arduino\\libraries\\DS1302_RTC" "-IC:\\Programy\\Arduino\\libraries\\NewliquidCrystal" "-IC:\\Users\\sitek\\OneDrive\\Pulpit\\libraries\\Time-master" "-IC:\\Programy\\Arduino\\libraries\\TimeAlarms-master" "C:\\Users\\sitek\\AppData\\Local\\Temp\\arduino_build_26787\\sketch\\MEGA_V8.0.ino.cpp" -o nul
Alternatives for DFRobot_QMC5883.h: [DFRobot_QMC5883-master]
ResolveLibrary(DFRobot_QMC5883.h)
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

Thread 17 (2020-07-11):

Mega Boot loop?? Time:(unknown day)

robotica72, 2020-07-11:
I flashed the mega code to one Arduino Mega and it was working, but that board had issues and stopped power up at all.

I just received a new Mega and when I flashed the code and monitor the serial output, its seems to be stuck in a boot loop:

ReP_AL Robot :V8.3
===================

Starting Mower Setup
===================
*** EEPROM Settings ***
*************************
Time:(unknown day) 2165-165-165 27:165:8⸮

ReP_AL Robot :V8.3
===================

Starting Mower Setup
===================
*** EEPROM Settings ***
*************************
Time:(unknown day) 2165-165-165 27:165:8⸮

ReP_AL Robot :V8.3
===================

Starting Mower Setup
===================
*** EEPROM Settings ***
*************************
Time:(unknown day) 2165-165-165 27:165:8

Any help on getting past this?

robotica72, 2020-07-11:
Hmm... Turns out it was the compass - I disconnected it and it boots..  Ill look at that soon

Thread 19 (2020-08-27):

// Calculate Amp Value from Charging Pins

esjaycc, 2020-08-27:
https://github.com/REPALphilread/ReP_AL-3D-Lawn-Mower/blob/aaa898cede5e9c0e36aad2cd24a6672aea8d0f8e/Mower%20Arduino%20Code/Mower_V8.8/Nano_V8.6/Nano_V8.6.ino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

2 times use of "VoltageAmp"

Change:

VoltageAmp = (RawValueAmp / 1024.0) * 5000; // Gets you mV
 AmpsTX =  ((VoltageAmp - ACSoffset) / mVperAmp);

 **Amps** = (RawWheelAmp / 1024.0) * 5000; // Gets you mV
 WheelAmpsTX =  ((**Amps** - ACSoffset) / mVperAmp);

Closed 2020-09-25.

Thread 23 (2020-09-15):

Fehler beim Überprüfen des Sketches MEGA_V8.9

esjaycc, 2020-09-15:
`Arduino: 1.8.13 (Windows 10), Board: "Arduino Mega or Mega 2560, ATmega2560 (Mega 2560)"

C:\Users\xxxxxxxx\Downloads\ReP_AL-3D-Lawn-Mower-master\Mower Arduino Code\Mower_V8.9\MEGA_V8.9\MEGA_V8.9.ino: In function 'void loop()':

MEGA_V8.9:621:67: error: 'TestforBoundaryWire' was not declared in this scope

 if (Mower_Docked == 1)                                            TestforBoundaryWire();                                  // Test is the boundary wire is live

                                                                   ^~~~~~~~~~~~~~~~~~~

MEGA_V8.9:636:67: error: 'TestforBoundaryWire' was not declared in this scope

 if (Mower_Parked == 1)                                            TestforBoundaryWire();

                                                                   ^~~~~~~~~~~~~~~~~~~

MEGA_V8.9:658:123: error: 'TestforBoundaryWire' was not declared in this scope

 if  (Mower_Running == 1)                                                                                                  TestforBoundaryWire();              // Test is the boundary wire is live

                                                                                                                           ^~~~~~~~~~~~~~~~~~~

MEGA_V8.9:660:123: error: 'Check_Wheel_Amps' was not declared in this scope

 if ((Mower_Running == 1) && (Wheel_Amp_Sensor_ON == 1) )                                                                  Check_Wheel_Amps();                 // Tests to see if the wheels are blocked.

                                                                                                                           ^~~~~~~~~~~~~~~~

C:\Users\xxxxxx\Downloads\ReP_AL-3D-Lawn-Mower-master\Mower Arduino Code\Mower_V8.9\MEGA_V8.9\MEGA_V8.9.ino:660:123: note: suggested alternative: 'Test_Wheel_Amps'

 if ((Mower_Running == 1) && (Wheel_Amp_Sensor_ON == 1) )                                                                  Check_Wheel_Amps();                 // Tests to see if the wheels are blocked.

                                                                                                                           ^~~~~~~~~~~~~~~~

                                                                                                                           Test_Wheel_Amps

MEGA_V8.9:661:123: error: 'Check_Wire_In_Out' was not declared in this scope

 if ((Mower_Running == 1) && (Wire_Detected == 1))                                                                         Check_Wire_In_Out();                // Test if the mower is in or out of the wire fence.

                                                                                                                           ^~~~~~~~~~~~~~~~~

C:\Users\xxxxxxx\Downloads\ReP_AL-3D-Lawn-Mower-master\Mower Arduino Code\Mower_V8.9\MEGA_V8.9\MEGA_V8.9.ino:661:123: note: suggested alternative: 'Check_GPS_In_Out'

 if ((Mower_Running == 1) && (Wire_Detected == 1))                                                                         Check_Wire_In_Out();                // Test if the mower is in or out of the wire fence.

                                                                                                                           ^~~~~~~~~~~~~~~~~

                                                                                                                           Check_GPS_In_Out

MEGA_V8.9:671:23: error: 'Receive_WIFI_Manuel_Commands' was not declared in this scope

 if (Manuel_Mode == 1) Receive_WIFI_Manuel_Commands();

                       ^~~~~~~~~~~~~~~~~~~~~~~~~~~~

C:\Users\xxxxx\Downloads\ReP_AL-3D-Lawn-Mower-master\Mower Arduino Code\Mower_V8.9\MEGA_V8.9\MEGA_V8.9.ino:671:23: note: suggested alternative: 'Get_WIFI_Commands'

 if (Manuel_Mode == 1) Receive_WIFI_Manuel_Commands();

                       ^~~~~~~~~~~~~~~~~~~~~~~~~~~~

                       Get_WIFI_Commands

C:\Users\xxxxxxx\Downloads\ReP_AL-3D-Lawn-Mower-master\Mower Arduino Code\Mower_V8.9\MEGA_V8.9\Manouvers.ino: In function 'void Manouver_Find_Wire_Track()':

Manouvers:222:3: error: 'TestforBoundaryWire' was not declared in this scope

   TestforBoundaryWire();                                                                    // Check to see that the wire is on.

   ^~~~~~~~~~~~~~~~~~~

Manouvers:233:7: error: 'UpdateWireSensor' was not declared in this scope

       UpdateWireSensor();

       ^~~~~~~~~~~~~~~~

Manouvers:239:7: error: 'PrintBoundaryWireStatus' was not declared in this scope

       PrintBoundaryWireStatus();

       ^~~~~~~~~~~~~~~~~~~~~~~

C:\Users\xxxxxx\Downloads\ReP_AL-3D-Lawn-Mower-master\Mower Arduino Code\Mower_V8.9\MEGA_V8.9\Manouvers.ino:239:7: note: suggested alternative: 'Print_Mower_Status'

       PrintBoundaryWireStatus();

       ^~~~~~~~~~~~~~~~~~~~~~~

       Print_Mower_Status

Manouvers:386:3: error: 'UpdateWireSensor' was not declared in this scope

   UpdateWireSensor();

   ^~~~~~~~~~~~~~~~

Manouvers:388:3: error: 'PrintBoundaryWireStatus' was not declared in this scope

   PrintBoundaryWireStatus();                                                                  // Prints of the status of the wire sensor readings

   ^~~~~~~~~~~~~~~~~~~~~~~

C:\Users\xxxxxx\Downloads\ReP_AL-3D-Lawn-Mower-master\Mower Arduino Code\Mower_V8.9\MEGA_V8.9\Manouvers.ino:388:3: note: suggested alternative: 'Print_Mower_Status'

   PrintBoundaryWireStatus();                                                                  // Prints of the status of the wire sensor readings

   ^~~~~~~~~~~~~~~~~~~~~~~

   Print_Mower_Status

C:\Users\xxxxxx\Downloads\ReP_AL-3D-Lawn-Mower-master\Mower Arduino Code\Mower_V8.9\MEGA_V8.9\Manouvers.ino: In function 'void Manouver_Turn_Around()':

Manouvers:501:9: error: 'Check_Wire_In_Out' was not declared in this scope

         Check_Wire_In_Out();

         ^~~~~~~~~~~~~~~~~

C:\Users\xxxxx\Downloads\ReP_AL-3D-Lawn-Mower-master\Mower Arduino Code\Mower_V8.9\MEGA_V8.9\Manouvers.ino:501:9: note: suggested alternative: 'Check_GPS_In_Out'

         Check_Wire_In_Out();

         ^~~~~~~~~~~~~~~~~

         Check_GPS_In_Out

Manouvers:505:11: error: 'TestforBoundaryWire' was not declared in this scope

           TestforBoundaryWire();

           ^~~~~~~~~~~~~~~~~~~

Manouvers:507:11: error: 'UpdateWireSensor' was not declared in this scope

           UpdateWireSensor();

           ^~~~~~~~~~~~~~~~

C:\Users\xxxxxx\Downloads\ReP_AL-3D-Lawn-Mower-master\Mower Arduino Code\Mower_V8.9\MEGA_V8.9\Manouvers.ino: In function 'void Manouver_Go_To_Charging_Station()':

Manouvers:929:61: error: 'Track_Perimeter_Wire_To_Dock' was not declared in this scope

   if ((Mower_Parked == 0) && (No_Wire_Found_Fwd == 0))      Track_Perimeter_Wire_To_Dock();

                                                             ^~~~~~~~~~~~~~~~~~~~~~~~~~~~

C:\Users\xxxxxx\Downloads\ReP_AL-3D-Lawn-Mower-master\Mower Arduino Code\Mower_V8.9\MEGA_V8.9\Manouvers.ino:929:61: note: suggested alternative: 'Perimeter_Wire_Enabled'

   if ((Mower_Parked == 0) && (No_Wire_Found_Fwd == 0))      Track_Perimeter_Wire_To_Dock();

                                                             ^~~~~~~~~~~~~~~~~~~~~~~~~~~~

                                                             Perimeter_Wire_Enabled

C:\Users\xxxxx\Downloads\ReP_AL-3D-Lawn-Mower-master\Mower Arduino Code\Mower_V8.9\MEGA_V8.9\Manouvers.ino: In function 'void Manouver_Exit_To_Zone_X()':

Manouvers:953:6: error: 'TestforBoundaryWire' was not declared in this scope

      TestforBoundaryWire();

      ^~~~~~~~~~~~~~~~~~~

Manouvers:961:31: error: 'Track_Wire_From_Dock_to_Zone_X' was not declared in this scope

        if (Mower_Parked == 0) Track_Wire_From_Dock_to_Zone_X();

                               ^~~~~~~~~~~~~~~~~~~~~~~~~~~~~~

C:\Users\xxxxxx\Downloads\ReP_AL-3D-Lawn-Mower-master\Mower Arduino Code\Mower_V8.9\MEGA_V8.9\Manouvers.ino: In function 'void Manouver_Outside_Wire_ReFind_Function()':

Manouvers:1004:5: error: 'UpdateWireSensor' was not declared in this scope

     UpdateWireSensor();

     ^~~~~~~~~~~~~~~~

Manouvers:1006:5: error: 'PrintBoundaryWireStatus' was not declared in this scope

     PrintBoundaryWireStatus();

     ^~~~~~~~~~~~~~~~~~~~~~~

C:\Users\xxxxx\Downloads\ReP_AL-3D-Lawn-Mower-master\Mower Arduino Code\Mower_V8.9\MEGA_V8.9\Manouvers.ino:1006:5: note: suggested alternative: 'Print_Mower_Status'

     PrintBoundaryWireStatus();

     ^~~~~~~~~~~~~~~~~~~~~~~

     Print_Mower_Status

C:\Users\xxxxxx\Downloads\ReP_AL-3D-Lawn-Mower-master\Mower Arduino Code\Mower_V8.9\MEGA_V8.9\Special.ino: In function 'void Specials_Find_Wire_Track()':

Special:85:3: error: 'TestforBoundaryWire' was not declared in this scope

   TestforBoundaryWire();                                                                    // Check to see that the wire is on.

   ^~~~~~~~~~~~~~~~~~~

Special:91:5: error: 'UpdateWireSensor' was not declared in this scope

     UpdateWireSensor();

     ^~~~~~~~~~~~~~~~

Special:96:5: error: 'PrintBoundaryWireStatus' was not declared in this scope

     PrintBoundaryWireStatus();

     ^~~~~~~~~~~~~~~~~~~~~~~

C:\Users\xxxxxx\Downloads\ReP_AL-3D-Lawn-Mower-master\Mower Arduino Code\Mower_V8.9\MEGA_V8.9\Special.ino:96:5: note: suggested alternative: 'Print_Mower_Status'

     PrintBoundaryWireStatus();

     ^~~~~~~~~~~~~~~~~~~~~~~

     Print_Mower_Status

Special:144:9: error: 'UpdateWireSensor' was not declared in this scope

         UpdateWireSensor();

         ^~~~~~~~~~~~~~~~

Special:146:9: error: 'PrintBoundaryWireStatus' was not declared in this scope

         PrintBoundaryWireStatus();

         ^~~~~~~~~~~~~~~~~~~~~~~

C:\Users\xxxxxx\Downloads\ReP_AL-3D-Lawn-Mower-master\Mower Arduino Code\Mower_V8.9\MEGA_V8.9\Special.ino:146:9: note: suggested alternative: 'Print_Mower_Status'

         PrintBoundaryWireStatus();

         ^~~~~~~~~~~~~~~~~~~~~~~

         Print_Mower_Status

C:\Users\xxxxxxx\Downloads\ReP_AL-3D-Lawn-Mower-master\Mower Arduino Code\Mower_V8.9\MEGA_V8.9\Test_Mower_Sketches.ino: In function 'void Test_Wheel_Amps()':

Test_Mower_Sketches:69:9: error: 'Calculate_Wheel_Amps' was not declared in this scope

         Calculate_Wheel_Amps();

         ^~~~~~~~~~~~~~~~~~~~

C:\Users\xxxxxx\Downloads\ReP_AL-3D-Lawn-Mower-master\Mower Arduino Code\Mower_V8.9\MEGA_V8.9\Test_Mower_Sketches.ino:69:9: note: suggested alternative: 'Max_Wheel_Amps'

         Calculate_Wheel_Amps();

         ^~~~~~~~~~~~~~~~~~~~

         Max_Wheel_Amps

Test_Mower_Sketches:70:9: error: 'Test_Check_Wheel_Amps' was not declared in this scope

         Test_Check_Wheel_Amps();

         ^~~~~~~~~~~~~~~~~~~~~

C:\Users\xxxxxx\Downloads\ReP_AL-3D-Lawn-Mower-master\Mower Arduino Code\Mower_V8.9\MEGA_V8.9\Test_Mower_Sketches.ino:70:9: note: suggested alternative: 'Test_Wheel_Amps'

         Test_Check_Wheel_Amps();

         ^~~~~~~~~~~~~~~~~~~~~

         Test_Wheel_Amps

C:\Users\xxxxxxx\Downloads\ReP_AL-3D-Lawn-Mower-master\Mower Arduino Code\Mower_V8.9\MEGA_V8.9\WIFI.ino: In function 'void Get_WIFI_Commands()':

WIFI:7:3: error: 'Receive_Data_From_NODEMCU' was not declared in this scope

   Receive_Data_From_NODEMCU();

   ^~~~~~~~~~~~~~~~~~~~~~~~~

C:\Users\xxxxxx\Downloads\ReP_AL-3D-Lawn-Mower-master\Mower Arduino Code\Mower_V8.9\MEGA_V8.9\WIFI.ino:7:3: note: suggested alternative: 'Receive_Data_From_TFT'

   Receive_Data_From_NODEMCU();

   ^~~~~~~~~~~~~~~~~~~~~~~~~

   Receive_Data_From_TFT

WIFI:9:3: error: 'Transmit_All_To_NODEMCU' was not declared in this scope

   Transmit_All_To_NODEMCU();

   ^~~~~~~~~~~~~~~~~~~~~~~

WIFI:12:34: error: a function-definition is not allowed here before '{' token

 void Receive_Data_From_NODEMCU() {

                                  ^

WIFI:22:37: error: a function-definition is not allowed here before '{' token

 void Receive_WIFI_Manuel_Commands() {

                                     ^
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

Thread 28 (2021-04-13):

TFT LCD setting not saving

avalder13, 2021-04-13:
For some reason, the mower will no longer save my settings and turn off/reset all sensors. I tried from updating to to the latest version to going back to previous ones to checking my wiring and so far no luck. Any idea what could be? Could it be that the MEGA on the TFT is busted of something?

Gh057-D3V, 2022-09-08:
I'm having the same issue. Did you ever figure it out?

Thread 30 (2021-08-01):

NodeMCU for wifi connection

ReinierGielen, 2021-08-01:
Can the NodeMCU for the wifi connection be replaced when I use an Arduino Mega with integrated Wifi ?
This would reduce a number of connections required.

Scriptman, 2022-02-11:
I fully agree.. An integration with ESPHome for Home Assistant would also be awesome

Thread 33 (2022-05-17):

problem with acs712

dvd72, 2022-05-17:
help , fix problem charging with acs712, show to display when is not connected parking station

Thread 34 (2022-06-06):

Mower only turns arond at one spot

Scriptman, 2022-06-06:
Hey,

I'm having issues for months now. The mower only turns right, dosn't enable blade, only turns right.
Stop buttons via TFT are not working.

Compass seems to work.
Gyro seems to work.
Sonar seems to work.

Pls help

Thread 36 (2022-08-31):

330 Monster docs indicate to install Sender Station v3, but no such version exists in repo

powneill, 2022-08-31:
In the [Arduino section](https://repalmakershop.com/pages/copy-of-3d-printed-mower-build-instructions-arduino) of the Monster 330 build guide, the instructions indicate to install  Sender Station v3.ino to the Uno/Nano, but this file does not exist within the [Perimeter Wire Transmitter ](https://github.com/REPALphilread/ReP_AL-3D-Lawn-Mower/tree/master/Perimeter%20Wire%20Transmitter)section of the repo.

It also indicates to use Sender_WEMOS.ino if using a WEMOS D1, but this also is not present in the repo.

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

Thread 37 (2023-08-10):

Problem to access to bmp on SD CARD from arduino mega

lebearnais64, 2023-08-10:
Hi
i format my SD card on FAT32
I copy all the file to the SDCARD

When i try to flash the TFT arduino code, I have the following error message

error: 'SdFatSoftSpi' does not name a type; did you mean 'SdFatConfig_h'?

Do you have an idea of this problem?

regards

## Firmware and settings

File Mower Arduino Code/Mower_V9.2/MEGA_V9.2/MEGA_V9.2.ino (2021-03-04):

// ReP_AL Lawn Mower Arduino Code
// Please make sure you have installed all the library files to the Arduino libraries folder
// You will need to unzip all the libraries from the GitHuB site.
// Instructions on how to do this are available on my webpage
// www.repalmakershop.com


#define BOARD_MEGA
//#define BOARD_DUE
//#define LCD_KEYPAD

//Libraries for Perimeter Wire Receiver
#include <Arduino.h>
#include <Wire.h>
//#include <EEPROM.h>
#include "drivers.h"
#include "adcman.h"
#include "perimeter.h"

#if defined(BOARD_Due)
#include <DueFlashStorage.h>
DueFlashStorage DueFlash; 
#endif



//Libraries for Real Time Clock
#include <stdio.h>
#include <DS1302.h>
#define DS3231_I2C_ADDRESS 0x68
// Convert normal decimal numbers to binary coded decimal
byte decToBcd(byte val)
{
  return ( (val / 10 * 16) + (val % 10) );
}
// Convert binary coded decimal to normal decimal numbers
byte bcdToDec(byte val)
{
  return ( (val / 16 * 10) + (val % 16) );
}


#if defined(LCD_KEYPAD)
//Libraries for ic2 Liquid Crystal
#include <LiquidCrystal_I2C.h>
LiquidCrystal_I2C lcd(0x27, 2, 1, 0, 4, 5, 6, 7, 3, POSITIVE);  // Enter the i2C address here lcd(_x__  e.g. lcd(0x27,
bool LCD_Screen_Keypad_Menu = 1;
#else
bool LCD_Screen_Keypad_Menu = 0;
#endif

//Libraries for the Mowing Calendar Function
#include <TimeLib.h>
#include <TimeAlarms.h>
AlarmId id;

//Compass Setup
#include <DFRobot_QMC5883.h>
DFRobot_QMC5883 compass;

//Perimeter Wire Pins
#define pinPerimeterLeft A5        // perimeter pin normally A5
#define pinPerimeterRight A4       // leave open
#define pinLED LED_BUILTIN

//GPS Fence Signal Pin
#define GPS_Fence_Signal_Pin A7
#define GPS_Lock_Pin A6

//Real Time Clock Pins
const int kCePin   = 29;  // RST
const int kIoPin   = 30;  // DAT
const int kSclkPin = 31;  // CLK

DS1302 rtc(kCePin, kIoPin, kSclkPin);

//Sonar Setup for Front Sonars 1-3
#define echoPin1 34   //S1               
#define trigPin1 35
#define echoPin2 36   //S2 
#define trigPin2 37
#define echoPin3 38   //S3
#define trigPin3 39

//Bumper Microswitches
#define Bumper_Switch_Frnt_RH  46               // Define Pin 47 on the MEGA to detect the microswitch
#define Bumper_Switch_Frnt_LH  47               // Define Pin 46 on the MEGA to detect the microswitch

#if defined(LCD_KEYPAD)
//Membrane Switch
#define Start_Key 50 //connect wire 1 to pin 2
#define Plus_Key 51  //connect wire 2 to pin 3
#define Minus_Key 52 //connect wire 3 to pin 4
#define Stop_Key 53  //connect wire 4 to pin 5
#endif



//Pin Setup for the wheel Motor Bridge Controller
//Motor A
#define ENAPin 7                // EN Pins need a digital pin with PWM
#define IN1Pin 6                // IN Pins dont need digital PWM 
#define IN2Pin 5
//Motor B
#define ENBPin 2                // EN Pins need a digital pin with PWM
#define IN3Pin 4                // IN Pins dont need digital PWM
#define IN4Pin 3

//Motor Blades
#define RPWM 8
#define L_EN 9
#define R_EN 10

//Relay Switch
#define Relay_Motors 24         // be careful that you really use PIN24.  The order is sometimes labelled
                                // so it looks like 24 is actually 22.

//Compass Level
#define X 3
#define Y 7
#define Z 5

// Tilt Sensors
#define Tilt_Angle A8           // measures the angle of the mower
#define Tilt_Orientation A9     // measures if the mower is upside down


//Global Variables

  //Perimeter Variables
  Perimeter perimeter;
  unsigned long nextTime = 0;
  int counter = 0;
  boolean inside = true;
  int Wire_Detected;

  int Loop_Cycle_Mowing = 0;             // was byte before.

  int Empty = 0;
  int Data1;
  int Data2;
  int Data3;
  int Data4;
  int Data5;
  int Data6;
  int Data7;
  
  //Sonar Variables
  long duration1 = 0;                     // Time required for the sonar ping to be recieved by the echo pin.
  long duration2 = 0;
  long duration3 = 0;

  int distance1 = 999;                    // Distance caculated  by the Sonar
  int distance2 = 999;
  int distance3 = 999;

  int distance_blockage;     

  int Sonar_Hit_1_Total;
  int Sonar_Hit_2_Total;
  int Sonar_Hit_3_Total;
  bool Sonar_Hit_Any_Total;
  bool Sonar_Hit_1 = 0;
  bool Sonar_Hit_2 = 0;
  bool Sonar_Hit_3 = 0;
  bool Sonar_Hit   = 0;

  // Bumper Variables
  bool Bump_Frnt_LH;
  bool Bump_Frnt_RH;
  bool Bumper;

  //Mower Status Variables
  bool Mower_Docked;
  bool Mower_Parked;
  bool Mower_Running;
  bool Mower_Parked_Low_Batt;
  int  Mower_Error;
  bool Manuel_Mode;
  int  Mower_Status_Value;
  int  Mower_Error_Value;
  bool Exiting_Dock;

  // Mower Running Data
  int Sonar_Status;
  //int Data_Sent_Wire;       // Counter
  int Bumper_Status;
  int Loops;
  int Compass_Steering_Status;
  int GYRO_Steering_Status;


  //Membrane Key Variables
  byte  Start_Key_X;
  byte  Plus_Key_X;
  byte  Minus_Key_X; 
  byte  Stop_Key_X;
  bool  Menu_Complete_Settings;
  bool  Menu_Complete_Alarms;
  bool  Menu_Complete_Sensors;
  bool  Menu_Complete_Motion;
  bool  Menu_Complete_NAVI;
  bool  Menu_Complete_Tracking;  
  bool  Menu_Complete;
  bool  Menu_NodeMCU_Complete;
  byte  Menu_Mode_Selection;
  int   Menu_View;
  int   Mow_Time_Set;
  int   Max_Options_Timing;
  int   Max_Options_Docked;
  int   Max_Options_Parked;
  int   Max_Options_Settings;
  int   Max_Options_Test;
  int   Max_Options_Alarms;
  int   Max_Options_Sensors;
  int   Max_Options_Motion;
  int   Max_Options_Tracking;
  int   Max_Options_NAVI;
  int   Max_Options_BETA;

  //Serial Communication
  float Volts;
  int   VoltsTX;
  float Volts_Last;
  int   Zero_Volts;
  float Amps;
  float VoltageAmp;
  int   RawValueAmp;
  int   RawValueVolt;
  int   Rain_Detected;
  int   Rain_Hit_Detected = 0;
  int   Charging;
  
  //float Battery_Voltage_Last;
  float Amps_Last;
  int   Volts_Outside_Reading;
  byte  OK_Nano_Data_Volt_Received; 
  byte  OK_Nano_Data_Charge_Received;
  byte  Charge_Hits = 0;
  byte  Docked_Hits = 0;
  bool  Charge_Detected_MEGA = 0;
  int   VoltsTX_Last;
  
  //Mow Calendar Variables
  byte Alarm_Hour_Now;
  byte Time_Hour;
  byte Time_Minute;
  byte Time_Second;
  byte Time_Day;
  byte Time_Month;
  byte Time_Year;
  byte Time_Date;
  bool Alarm_Timed_Mow_ON = 0;
  byte Alarm_Timed_Mow_Hour;                         // Mowing Hour Number 3
  byte Alarm_Timed_Mow_Minute;                       // Alarm minute 3

  int Alarm_1_Saved_EEPROM;
  int Alarm_2_Saved_EEPROM;
  int Alarm_3_Saved_EEPROM;

  String dayAsString(const Time::Day day) {
    switch (day) {
      case Time::kSunday: return "Sunday";
      case Time::kMonday: return "Monday";
      case Time::kTuesday: return "Tuesday";
      case Time::kWednesday: return "Wednesday";
      case Time::kThursday: return "Thursday";
      case Time::kFriday: return "Friday";
      case Time::kSaturday: return "Saturday";
      }
  return "(unknown day)";
  }

  //Perimeter Wire Tracking
  int I; 
  int Track_Wire_Itterations;
  bool Outside_Wire;
  byte Exit_Zone;
  int MAG_Now;
  int MAG_OUT_Stop;
  int MAG_IN_Stop;
  int MAG_TURN;
  int MAG_Average_Start;
  int MAG_Last;
  byte Outside_Wire_Count = 0;
  int Tracking_Wire = 0;
  bool Wire_ON_Printed;
  int Wire_Off;
  int Wire_Refind_Tries = 0;

  int Tracking_Turn_Left;
  int Tracking_Turn_Right;
  bool Mower_Track_To_Charge;
  bool Mower_Track_To_Exit;

  bool Abort_Wire_Find;
  bool No_Wire_Found_Fwd;
  bool No_Wire_Found_Bck;
  int  Wire_Find_Attempt = 0; 

  int  PWM_Right;
  int  PWM_Left;
  int  MAG_Goal;
  int  MAG_Error;
  int  MAG_Start;
  byte PWM_Blade_Speed_Min;
  byte PWM_Blade_Speed_Max;
  bool Blade_Override = 0;

  //Compass Variables
  float   Compass_Heading_Degrees;
  float   Heading;
  bool    Compass_Heading_Locked = 0;
  float   Heading_Lock;
  int     Heading_Upper_Limit_Compass;
  int     Heading_Lower_Limit_Compass;
  float   Compass_Target;
  int     Compass_Leg = 0;
  int     Turn_Adjust = 0;
  int     error = 0;
  float   Calb_XAxis;
  float   Calb_YAxis;
  float   Calb_ZAxis;
  int     Tilt_X;
  int     Tilt_Y;
  int     Tilt_Z;
  float   X_Tilt;
  float   Y_Tilt;
  float   Z_Tilt;
  int     Compass_Detected;
  Vector  norm;

  //GY-521 GYRO
  bool    GYRO_Heading_Locked = 0;
  int     GYRO_Angle;
  const int MPU_addr=0x69;
  int16_t AcX,AcY,AcZ,Tmp,GyX,GyY,GyZ, Temp;
  int GYRO_Angle_X;
  int GYRO_Angle_Y;
  int GYRO_Angle_Z;

  char tmp_str[7]; // temporary variable used in convert function

  // converts int16 to string. Moreover, resulting strings will have the same length in the debug monitor.
  char* convert_int16_to_str(int16_t i) { 
  sprintf(tmp_str, "%6d", i);
  return tmp_str;
  }

  int minVal=265;
  int maxVal=402;

  // Pattern Mow
  int Spiral_Mow = 1;
  int Linking_Section;
  int Leg = 1;
  float Compass_Last;
  bool Wire_Found;  

  // GPS
  bool GPS_Inside_Fence = 1;
  int GPS_Fence_Signal;
  int GPS_Lock_Signal;
  bool GPS_Lock_OK;

  //Wire Track Printer
  int PrintInMax;
  int PrintInMid;
  int PrintInMin;
  int PrintOutMin;
  int PrintOutMid;
  int PrintOutMax;
  int PrintMAG_Now;

  // Tilt Sensor
  int Tilt_Angle_Sensed = 1;          // reads the Tilt Angle sensor
  int Tilt_Orientation_Sensed;    // reads the Tilt Orientation sensor

  //WIFI Variables
  float val_WIFI;

  // TFT
  int  TFT_Menu_Command; 
  bool Menu_Complete_TFT;
  bool Mower_Is_Docking;
  bool Turn_To_Home;
  bool Find_Wire_Track;
  bool Go_To_Charging_Station;

  // Wheel Amp Sensors
  int    RawWheelAmp;
  int    Wheel_Blocked;
  float  WheelAmps;
  int    Wheel_Blocked_Count;
  

 
/***********************************************************************************************

                   SETUP OF MOWER

  The following setup parameters will setup the mower for your garden
  Turn on or off the settings to defien how you like the mower to behave.
  
  Settings marked with EEPROM can be adjusted using the mower LCD menu.  Once changes and saved
  the EEPROM settings will override the settings in this menu.  
  
  To clear these settings you need to clear the EEPROM
    
  1 = Turned ON      0 = Turned OFF       Value = Value set for variable.
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
void loop() {

if (TFT_Screen_Menu == 1)                                 Check_TFT_Serial_Input();   // Check the TFT Serial for any input command.
if ((TFT_Screen_Menu == 1) && (TFT_Menu_Command > 1))     Activate_TFT_Menu();        // If TFT Menu has requested an input, TX or RX that input.

// Read the Serial Ports for Data
Read_Serial1_Nano();                                                                  // Read the Serial data from the nano
Print_Mower_Status();                                                                 // Update the Serial monitor with the current mower status.


// Mower is docked, docking station is enabled and waiting for a command to leave and mow.
if ((Mower_Docked == 1) && (LCD_Screen_Keypad_Menu == 1))         Print_LCD_Volt_Info();                                  // Print the voltage to the LCD screen
if  (Mower_Docked == 1)                                           Check_if_Charging();
if ((Mower_Docked == 1) && (LCD_Screen_Keypad_Menu == 1))         Print_LCD_Info_Docked();                                // Print information to the LCD screen
if ((Mower_Docked == 1) && (LCD_Screen_Keypad_Menu == 1))         Print_Time_On_LCD(); 
if ((Mower_Docked == 1) && (LCD_Screen_Keypad_Menu == 1))         Check_Membrane_Switch_Input_Docked();                   // Check the membrane buttons for any input
if ((Mower_Docked == 1) && (GPS_Enabled == 1))                    Check_GPS_In_Out();                                     // Get the GPS Signal In / Out of Fence                                
if (Mower_Docked == 1)                                            TestforBoundaryWire();                                  // Test is the boundary wire is live                                 
if (Mower_Docked == 1)                                            Manouver_Dock_The_Mower();
if (Mower_Docked == 1)                                            Print_Time_On_Serial_Monitor();
if (Mower_Docked == 1)                                            Display_Next_Alarm();
if (Mower_Docked == 1)                                            Activate_Alarms();
if ((Mower_Docked == 1) && (TFT_Screen_Menu == 1))                Send_Mower_Docked_Data();                               // Send Data to TFT Display


// Mower is Parked ready to be started / re-started / or the mower has no docking station enabled.
if ((Mower_Parked == 1) && (LCD_Screen_Keypad_Menu == 1))         Print_LCD_Volt_Info();                                  // Print the voltage to the LCD screen
if (Mower_Parked == 1)                                            Check_if_Charging();
if (Mower_Parked == 1)                                            Check_if_Raining_From_Nano ();                          // Checks if the water sensor detects Rain
if ((Mower_Parked == 1) && (LCD_Screen_Keypad_Menu == 1))         Print_LCD_Info_Parked();                                // Print information to the LCD screen
if ((Mower_Parked == 1) && (LCD_Screen_Keypad_Menu == 1))         Check_Membrane_Switch_Input_Parked();                   // Check the membrane buttons for any input
if ((Mower_Parked == 1) && (GPS_Enabled == 1))                    Check_GPS_In_Out();
if (Mower_Parked == 1)                                            TestforBoundaryWire();
if (Mower_Parked == 1)                                            Manouver_Park_The_Mower();
if ((Mower_Parked == 1) && (TFT_Screen_Menu == 1))                Send_Mower_Docked_Data();                               // Send Data to TFT Display


// Mower is Parked with Low Battery needing manuel charging
if ((Mower_Parked_Low_Batt == 1) && (LCD_Screen_Keypad_Menu == 1)) Print_LCD_Volt_Info();                                  // Print the battery voltage
if ((Mower_Parked_Low_Batt == 1) && (LCD_Screen_Keypad_Menu == 1)) Print_Recharge_LCD();                                   // Print re-charge on the LCD screen
if ((Mower_Parked_Low_Batt == 1) && (LCD_Screen_Keypad_Menu == 1)) Check_Membrane_Switch_Input_Parked();
// Lost mower is put into standby mode

if ((Mower_Error == 1)  && (LCD_Screen_Keypad_Menu == 1))         Print_Mower_Error();                     // Safety mode incase the mower is lostor in an error state
if ((Mower_Error == 1)  && (LCD_Screen_Keypad_Menu == 1))         Check_Membrane_Switch_Input_Parked();
if ((Mower_Error == 1)  && (TFT_Screen_Menu == 1))                Send_Mower_Error_Data();                               // Send Data to TFT Display


// Mower is running cutting the grass.
if ((Mower_Running == 1) && (LCD_Screen_Keypad_Menu == 1))                                                                Print_LCD_Volt_Info();              // Print the voltage to the LCD screen
if  (Mower_Running == 1)                                                                                                  Process_Volt_Information();         // Take action based on the voltage readings
if  (Mower_Running == 1)                                                                                                  Check_if_Raining_From_Nano();       // Test the rain sensor for rain. If detected sends the mower home
if ((Mower_Running == 1) && (LCD_Screen_Keypad_Menu == 1))                                                                Check_Membrane_Keys_Running();      // Check to see if the mower needs to be stopped via keypad
if  (Mower_Running == 1)                                                                                                  Check_Timed_Mow();                  // Check to see if the time to go home has come.
if  (Mower_Running == 1)                                                                                                  TestforBoundaryWire();              // Test is the boundary wire is live
if  (Mower_Running == 1)                                                                                                  Check_Tilt_Tip_Angle();             // Tests to see if the mower is overturned.
if ((Mower_Running == 1) && (Wheel_Amp_Sensor_ON == 1) )                                                                  Check_Wheel_Amps();                 // Tests to see if the wheels are blocked.
if ((Mower_Running == 1) && (Wire_Detected == 1))                                                                         Check_Wire_In_Out();                // Test if the mower is in or out of the wire fence.
if ((Mower_Running == 1) && (GPS_Enabled == 1))                                                                           Check_GPS_In_Out();                 // Test is the GPS Fence has been crossed
if ((Mower_Running == 1) && (Wire_Detected == 1) && (Outside_Wire == 0))                                                  Check_Sonar_Sensors();              // If the mower is  the boundary wire check the sonars for obsticles and prints to the LCD
if ((Mower_Running == 1) && (Wire_Detected == 1) && (Outside_Wire == 0) && (Sonar_Hit == 0))                              Manouver_Mow_The_Grass();           // Inputs to the wheel motors / blade motors according to surroundings 
if ((Mower_Running == 1) && (Wire_Detected == 1) && (Outside_Wire == 0) && (Sonar_Hit == 0))                              Check_Bumper();                     // If the mower is  the boundary wire check the Bumper for activation
if ((Mower_Running == 1) && (Wire_Detected == 1) && ((Outside_Wire == 1) || (Bumper == 1))  && (Loop_Cycle_Mowing > 0))   Manouver_Turn_Around();             // If the bumper is activated or the mower is outside the boundary wire turn around
if ((Mower_Running == 1) && (GPS_Enabled == 1) && (GPS_Inside_Fence == 0))                                                Manouver_Turn_Around();             // If the GPS Fence is activated Turn Around
if ((Mower_Running == 1) && (Wire_Detected == 1) && (Outside_Wire == 0) && (Sonar_Hit == 1))                              Manouver_Turn_Around_Sonar();       // If sonar hit is detected and mower is  the wire, manouver around obsticle 

// WIFI Commands from and to APP
if (Manuel_Mode == 1) Receive_WIFI_Manuel_Commands();
if (Manuel_Mode == 1) Print_LCD_Info_Manuel();
if ((WIFI_Enabled == 1) && (Manuel_Mode == 0)) Get_WIFI_Commands();                                   // TX and RX data from NodeMCU

Serial.println(); 
  
}  // End Loop

  

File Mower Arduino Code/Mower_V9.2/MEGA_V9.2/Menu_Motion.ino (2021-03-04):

// Motion SETTINGS MENU

#if defined(LCD_KEYPAD)

// Test to displyed on the LCD screen when using the membrane key menus
void Print_LCD_Menu_Motion(byte LCD_Menu_Motion) {
  if (LCD_Menu_Motion == 1) lcd.print(F("Wheel Speed"));
  if (LCD_Menu_Motion == 2) lcd.print(F("Blade Speed"));  //+need to add ON/OFF
  if (LCD_Menu_Motion == 3) lcd.print(F("Blades ON/OFF"));
  if (LCD_Menu_Motion == 4) lcd.print(F("Turn Angles"));
  if (LCD_Menu_Motion == 5) lcd.print(F("Reverse Dist"));
  if (LCD_Menu_Motion == 6) lcd.print(F("Max Length"));
  if (LCD_Menu_Motion == 7) lcd.print(F("Pattern Mow"));
  if (LCD_Menu_Motion == 8) lcd.print(F("-SPARE-"));

  
  Max_Options_Motion = 8;
  }


void Print_Membrane_Switch_Input_Motion() {
     Read_Membrane_Keys();
     Menu_Complete_Motion = 1;
     Menu_Mode_Selection = 0;
     Menu_View = 0;

      Serial.println();
      Serial.println(F("Motion Menu Activated"));
      Menu_Complete_Motion = false;                                // Menu complete will return to the normal loop
      lcd.clear();
      delay(5);
      
      while (Menu_Complete_Motion == false) {                      // holds the program in a loop until a selection has been made in the membrane button menu
        if (Menu_View == 0) {
          lcd.setCursor(1,0);
          Print_LCD_Menu_Motion(1);
          lcd.setCursor(1,1);
          Print_LCD_Menu_Motion(2);
          }
        // Gets the values again from the keys
        Read_Membrane_Keys();
        delay(100);
             
        if(!Start_Key_X){
          Menu_Complete_Motion = true;
          Serial.println(F("Start key is pressed"));
          Activate_Menu_Option_Motion();
          lcd.clear();
          
          }
        if(!Plus_Key_X) {
          Serial.println(F("+ key is pressed"));
          Menu_View = Menu_View - 1;
          Run_Menu_Order_Motion();
          }
        if(!Minus_Key_X) {
          Menu_View = Menu_View + 1;
          Run_Menu_Order_Motion();
        }
        if(!Stop_Key_X){
          Serial.println(F("Stop key is pressed"));
          Menu_Complete_Motion = true;
          lcd.clear();
          lcd.setCursor(0,0);
          lcd.print("Exit Motion");
          delay(1000);
          lcd.clear();          
          Menu_Mode_Selection = 0;
          }
      }
    }

    


// Code to scroll the menu and print the menu options in the LCD
 void Run_Menu_Order_Motion() {
     if (Menu_View > Max_Options_Motion) Menu_View = Menu_View -1;
     if (Menu_View < 0) Menu_View = Menu_View + 1;      
     Serial.print(F("- key is pressed "));
     lcd.clear();
     lcd.setCursor(1,0);
     Print_LCD_Menu_Motion(Menu_View);
     lcd.setCursor(1,1);
     Print_LCD_Menu_Motion( Menu_View + 1);
     lcd.setCursor(0,0);
     lcd.print(">");
     Menu_Mode_Selection = Menu_View;
     Serial.print(F("Menu View : "));
     Serial.print(Menu_View);
     Serial.print(F("| Menu Selection"));
     Serial.println(Menu_Mode_Selection);
     delay(100);
     }

     
// Defines the actions when that option is selected with the keypad.
void Activate_Menu_Option_Motion() {


   if (Menu_Mode_Selection == 1) {
       // LH and RH wheel SPEED PWM settings
     
       int Set = 1;
       Menu_Mode_Selection = 0;
       lcd.clear();
       delay(100);
       lcd.setCursor(0,0);
       lcd.print(F("Set Wheel PWM"));
       lcd.setCursor(0,1);
       lcd.print(F("LH & RH Wheels"));
       delay(1000);
       lcd.clear();
       lcd.setCursor(0,0);
       lcd.print(F("> LH_PWM: "));
       lcd.print(PWM_MaxSpeed_LH);
       lcd.setCursor(0,1);
       lcd.print(F("  RH_PWM: "));
       lcd.print(PWM_MaxSpeed_RH);
       Menu_Complete_Motion = false;
       while (Menu_Complete_Motion == false) {
             Read_Membrane_Keys();
             delay(100);
             //Enter Code Here to Cycle until stop key is pressed.
             if(!Start_Key_X){
             
             if (Set == 2) { 
               Serial.println(F("Settings Saved"));
               Menu_Complete_Motion = true;
               lcd.clear();
               lcd.setCursor(0,0);
               lcd.print(F("Wheel PWM"));
               lcd.setCursor(0,1);
               lcd.print(F("SAVED"));
               delay(2000);
               lcd.clear();          
               EEPROM.write(13, 1);
               EEPROM.write(14, PWM_MaxSpeed_LH);
               EEPROM.write(15, 1);
               EEPROM.write(16, PWM_MaxSpeed_RH);
               Menu_Mode_Selection = 0;
               }
              
             if (Set == 1) {
                lcd.clear();
                lcd.setCursor(0,0);
                lcd.print(F("  LH_PWM: "));
                lcd.print(PWM_MaxSpeed_LH);
                lcd.setCursor(0,1);
                lcd.print(F("> RH_PWM: "));
                lcd.print(PWM_MaxSpeed_RH);   
                Set = Set + 1;          
                }


             }
             if (!Plus_Key_X) {
               if (Set == 1) {
                 PWM_MaxSpeed_LH = PWM_MaxSpeed_LH + 1;
                 if (PWM_MaxSpeed_LH > 255) PWM_MaxSpeed_LH = 255;
                 lcd.clear();
                 lcd.setCursor(0,0);
                 lcd.print(F("> LH_PWM: "));
                 lcd.print(PWM_MaxSpeed_LH);
                 lcd.setCursor(0,1);
                 lcd.print(F("  RH_PWM: "));
                 lcd.print(PWM_MaxSpeed_RH);
                 }
               if (Set == 2) {
                 PWM_MaxSpeed_RH = PWM_MaxSpeed_RH + 1;
                 if (PWM_MaxSpeed_RH > 255) PWM_MaxSpeed_RH = 255;
                 lcd.clear();
                 lcd.setCursor(0,0);
                 lcd.print(F("  LH_PWM: "));
                 lcd.print(PWM_MaxSpeed_LH);
                 lcd.setCursor(0,1);
                 lcd.print(F("> RH_PWM: "));
                 lcd.print(PWM_MaxSpeed_RH);       
                 }
               }
             if (!Minus_Key_X) {
               if (Set == 1) {
                 PWM_MaxSpeed_LH = PWM_MaxSpeed_LH - 1;
                 if (PWM_MaxSpeed_LH < 0) PWM_MaxSpeed_LH = 0;
                 lcd.setCursor(0,0);
                 lcd.setCursor(0,0);
                 lcd.print(F("> LH_PWM: "));
                 lcd.print(PWM_MaxSpeed_LH);
                 lcd.setCursor(0,1);
                 lcd.print(F("  RH_PWM: "));
                 lcd.print(PWM_MaxSpeed_RH);
                 }
               if (Set == 2) {
                 PWM_MaxSpeed_RH = PWM_MaxSpeed_RH - 1;
                 if (PWM_MaxSpeed_RH < 0) PWM_MaxSpeed_RH = 0;
                 lcd.setCursor(0,0);
                 lcd.setCursor(0,0);
                 lcd.print(F("  LH_PWM: "));
                 lcd.print(PWM_MaxSpeed_LH);
                 lcd.setCursor(0,1);
                 lcd.print(F("> RH_PWM: "));
                 lcd.print(PWM_MaxSpeed_RH);       
                 }
               }
     
             
     }
     }
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

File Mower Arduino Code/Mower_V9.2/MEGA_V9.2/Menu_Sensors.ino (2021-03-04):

// SENSORS SETTINGS MENU

#if defined(LCD_KEYPAD)


// Test to displyed on the LCD screen when using the membrane key menus
void Print_LCD_Menu_Sensors(byte LCD_Menu_Sensors) {
  if (LCD_Menu_Sensors == 1)  lcd.print(F("SONAR ON/OFF"));
  if (LCD_Menu_Sensors == 2)  lcd.print(F("SONAR Distance"));
  if (LCD_Menu_Sensors == 3)  lcd.print(F("SONAR Sensitivity"));   
  if (LCD_Menu_Sensors == 4)  lcd.print(F("Battery Min/Max"));      // add max
  if (LCD_Menu_Sensors == 5)  lcd.print(F("Batt Sensitivity"));
  if (LCD_Menu_Sensors == 6)  lcd.print(F("WIRE ON/OFF"));   
  if (LCD_Menu_Sensors == 7)  lcd.print(F("RAIN ON/OFF"));
  if (LCD_Menu_Sensors == 8)  lcd.print(F("Rain Sensitivity"));
  if (LCD_Menu_Sensors == 9)  lcd.print(F("WIFI ON/OFF"));
  if (LCD_Menu_Sensors == 10)  lcd.print(F("Bumper ON/OFF"));
  if (LCD_Menu_Sensors == 11) lcd.print(F("ANGLE ON/OFF"));
  if (LCD_Menu_Sensors == 12)  lcd.print(F("TIP ON/OFF"));
  if (LCD_Menu_Sensors == 13) lcd.print(F(""));
  
  Max_Options_Sensors = 13;
  }


void Print_Membrane_Switch_Input_Sensors() {
     Read_Membrane_Keys();
     Menu_Complete = 1;
     Menu_Mode_Selection = 0;
     Menu_View = 0;

      Serial.println();
      Serial.println(F("Sensors Menu Activated"));
      Menu_Complete_Sensors = false;                                // Menu complete will return to the normal loop
      lcd.clear();
      delay(5);
      
      while (Menu_Complete_Sensors == false) {                      // holds the program in a loop until a selection has been made in the membrane button menu
        if (Menu_View == 0) {
          lcd.setCursor(1,0);
          Print_LCD_Menu_Sensors(1);
          lcd.setCursor(1,1);
          Print_LCD_Menu_Sensors(2);
          }
        // Gets the values again from the keys
        Read_Membrane_Keys();
        delay(100);
             
        if(!Start_Key_X){
          Menu_Complete_Sensors = true;
          Serial.println(F("Start key is pressed"));
          Activate_Menu_Option_Sensors();
          lcd.clear();
          
          }
        if(!Plus_Key_X) {
          Serial.println(F("+ key is pressed"));
          Menu_View = Menu_View - 1;
          Run_Menu_Order_Sensors();
          }
        if(!Minus_Key_X) {
          Menu_View = Menu_View + 1;
          Run_Menu_Order_Sensors();
        }
        if(!Stop_Key_X){
          Serial.println(F("Stop key is pressed"));
          Menu_Complete_Sensors = true;
          lcd.clear();
          lcd.setCursor(0,0);
          lcd.print("Exit Sensors");
          delay(1000);
          lcd.clear();          
          Menu_Mode_Selection = 0;
          }
      }
    }

    


// Code to scroll the menu and print the menu options in the LCD
 void Run_Menu_Order_Sensors() {
     if (Menu_View > Max_Options_Sensors) Menu_View = Menu_View -1;
     if (Menu_View < 0) Menu_View = Menu_View + 1;      
     Serial.print(F("- key is pressed "));
     lcd.clear();
     lcd.setCursor(1,0);
     Print_LCD_Menu_Sensors(Menu_View);
     lcd.setCursor(1,1);
     Print_LCD_Menu_Sensors(Menu_View + 1);
     lcd.setCursor(0,0);
     lcd.print(">");
     Menu_Mode_Selection = Menu_View;
     Serial.print(F("Menu View : "));
     Serial.print(Menu_View);
     Serial.print(F("| Menu Selection"));
     Serial.println(Menu_Mode_Selection);
     delay(100);
     }

     
// Defines the actions when that option is selected with the keypad.
void Activate_Menu_Option_Sensors() {

     if (Menu_Mode_Selection == 1) {
       // SONAR ON/OFF
     
       int Set = 1;
       Menu_Mode_Selection = 0;
       lcd.clear();
       delay(100);
       lcd.setCursor(0,0);
       lcd.print(F("SONAR Active Y/N"));
       lcd.setCursor(0,1);
       lcd.print(F(">S2:"));
       if (Sonar_2_Activate == 1) lcd.print("Y");
       if (Sonar_2_Activate == 0) lcd.print("N");
       lcd.print(F(" S1:"));
       if (Sonar_1_Activate == 1) lcd.print("Y");
       if (Sonar_1_Activate == 0) lcd.print("N");
       lcd.print(F(" S3:"));
       if (Sonar_3_Activate == 1) lcd.print("Y");
       if (Sonar_3_Activate == 0) lcd.print("N");
       delay(2000);

       Menu_Complete_Sensors = false;
       while (Menu_Complete_Sensors == false) {
             Read_Membrane_Keys();
             delay(100);
             //Enter Code Here to Cycle until stop key is pressed.
             if(!Start_Key_X){
             
             if (Set == 3) {
               lcd.clear(); 
               lcd.setCursor(0,0);
               lcd.print(F("SONAR"));
               lcd.setCursor(0,1);
               lcd.print(F("Settings Saved"));
               delay(2000);            
               EEPROM.write(37, 1);
               EEPROM.write(38, Sonar_1_Activate);
               EEPROM.write(39, 1);
               EEPROM.write(40, Sonar_2_Activate);
               EEPROM.write(41, 1);
               EEPROM.write(42, Sonar_3_Activate);
               Menu_Mode_Selection = 0;
               Menu_Complete_Sensors = true;
               }

             
             if (Set == 2) { 
                lcd.clear();
                lcd.setCursor(0,0);
                lcd.print(F("Y = Yes  N = No"));
                lcd.setCursor(0,1);
                lcd.print(F(" S2:"));
                if (Sonar_2_Activate == 1) lcd.print("Y");
                if (Sonar_2_Activate == 0) lcd.print("N");
                lcd.print(F(" S1:"));
                if (Sonar_1_Activate == 1) lcd.print("Y");
                if (Sonar_1_Activate == 0) lcd.print("N");
                lcd.print(F(">S3:"));
                if (Sonar_3_Activate == 1) lcd.print("Y");
                if (Sonar_3_Activate == 0) lcd.print("N");
                Set = Set + 1;         
               }
            
             if (Set == 1) { 
                lcd.clear();
                lcd.setCursor(0,0);
                lcd.print(F("Y = Yes  N = No"));
                lcd.setCursor(0,1);
                lcd.print(F(" S2:"));
                if (Sonar_2_Activate == 1) lcd.print("Y");
                if (Sonar_2_Activate == 0) lcd.print("N");
                lcd.print(F(">S1:"));
                if (Sonar_1_Activate == 1) lcd.print("Y");
                if (Sonar_1_Activate == 0) lcd.print("N");
                lcd.print(F(" S3:"));
                if (Sonar_3_Activate == 1) lcd.print("Y");
                if (Sonar_3_Activate == 0) lcd.print("N");
                Set = Set + 1;         
               }
             }
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
